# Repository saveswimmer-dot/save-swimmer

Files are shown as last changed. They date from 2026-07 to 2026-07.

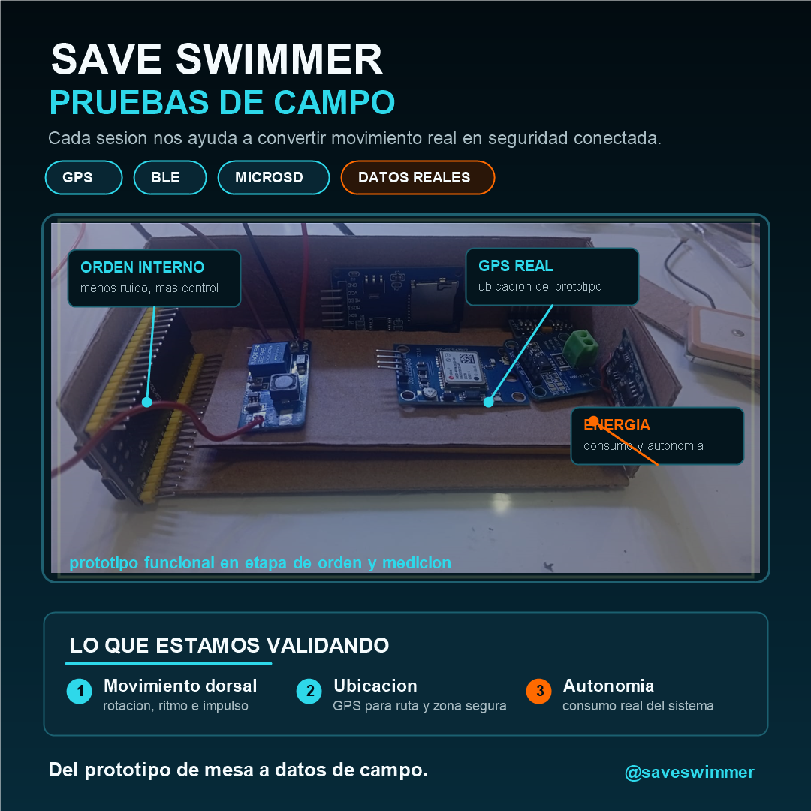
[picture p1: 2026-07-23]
redes/SS-POST-PRUEBAS-CAMPO-V004.png

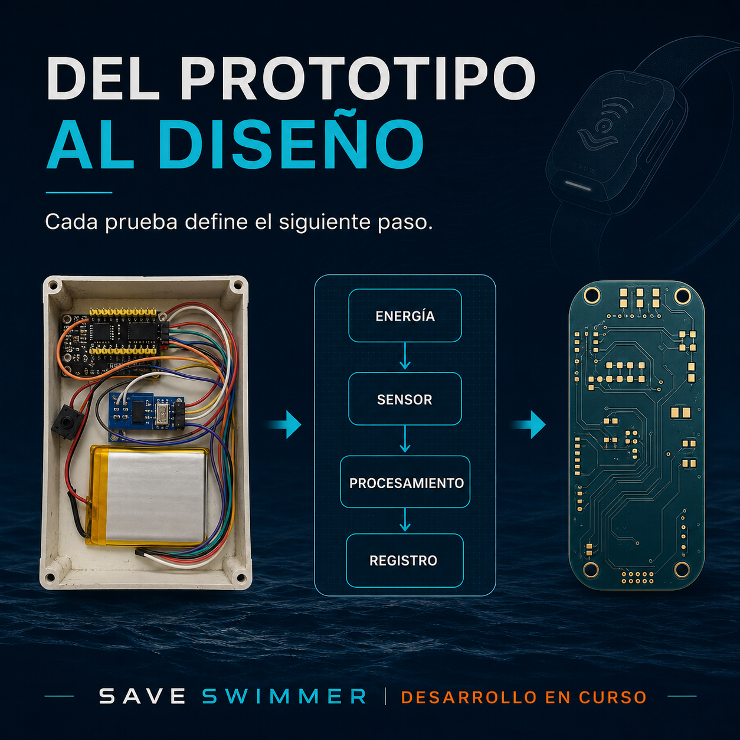
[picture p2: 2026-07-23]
campana_financiamiento/post_redes_del_prototipo_al_diseno_v001.png

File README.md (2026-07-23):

# Save Swimmer

Connected safety and monitoring for open-water swimmers.

Save Swimmer is a working early prototype of a connected safety and monitoring system for open-water swimmers. The project explores how a dorsal wearable, Android apps, GPS, motion sensors, local logging, and session reports can provide more context than location alone.

This is not a certified rescue device. It is a prototype for validating data capture, swimmer context, app workflows, and future early-warning behavior.

## Why It Matters

Open-water swimmers often train far from shore. Family members, coaches, or event organizers may know the intended route, but not the swimmer's real context in the water.

GPS can show location and speed, but it does not always explain whether the swimmer is moving normally, drifting, pausing, rotating differently, or showing unusual movement patterns. Save Swimmer focuses on connected awareness: location, movement, session state, and trusted-contact workflows.

## Current Prototype

The current project includes:

- a dorsal wearable prototype;
- ESP32-based firmware;
- IMU/motion sensor capture;
- GPS/session data capture;
- Bluetooth LE communication;
- microSD CSV logging;
- Android app concepts for athlete, family, coach, and field testing;
- CSV/session analysis tools;
- report and visualization work for rotation, alignment, movement, and GPS speed;
- hardware, enclosure, and wearable-mounting design notes.

## Repository Map

- `SaveSwimmer_Lite_BLE_Viewer_V054/` - current firmware prototype sketch.
- `android/SaveSwimmerAthlete/` - athlete-facing Android app prototype.
- `android/SaveSwimmerFamily/` - family/emergency-contact app prototype.
- `android/SaveSwimmerCoachLive/` - optional coach/event live monitoring prototype.
- `android/SaveSwimmerFieldViewer/` - field testing and live data review app.
- `backend/` - backend/ngrok test support and local data.
- `herramientas/` - CSV/reporting and analysis tools.
- `reportes_atleta/` - athlete report generation work.
- `datasets/` - test data and evidence datasets.
- `diseno_3d/` - enclosure and 3D mockup files.
- `diseno_arnes/` - dorsal harness/mounting pattern for field testing.
- `outputs/` - project notes, cost analysis, and technical planning documents.
- `redes/` and `social_posts/` - project media and public communication drafts.

## Built With

- Codex
- GPT-5.6
- Android
- Java
- ESP32
- Arduino
- Bluetooth LE
- GPS
- microSD
- CSV
- IoT
- Wearable prototyping
- Sensor data analysis
- Data visualization

## How Codex And GPT-5.6 Were Used

Codex and GPT-5.6 were used as an active development partner across the project, including:

- firmware iteration and test planning;
- Android APK versioning, UI adjustments, and debugging;
- BLE/GPS/session workflow design;
- CSV interpretation and report-generation logic;
- biomechanical reference analysis for rotation and alignment context;
- product positioning and safety-language refinement;
- Devpost submission drafting;
- README and documentation preparation;
- hardware roadmap, cost modeling, and prototype planning.

The project existed as a broader idea before OpenAI Build Week, but it was meaningfully extended during the hackathon period with Codex-assisted work across apps, firmware, reports, product documentation, and submission materials.

## Testing Notes

This project combines software and physical prototype work. Judges can review the Android source/APKs, firmware sketch, CSV/reporting tools, documentation, and demo video. The hardware prototype is intended for controlled field validation and is not presented as a finished commercial product.

Recommended review path:

1. Watch the demo video.
2. Read this README.
3. Review the current firmware in `SaveSwimmer_Lite_BLE_Viewer_V054/`.
4. Review Android prototypes under `android/`.
5. Review CSV/reporting outputs and project documentation.

## Safety Note

Save Swimmer is an early-stage prototype. It does not guarantee rescue, replace lifeguards, replace emergency services, or certify swimmer safety. Its current purpose is to validate data capture, connected monitoring workflows, and the product direction for future open-water safety support.

## Next Steps

- More controlled pool and open-water tests.
- Improved wearable mounting and waterproofing.
- Cleaner hardware layout.
- Better live synchronization.
- Improved GPS and motion interpretation.
- Family/emergency-contact workflow refinement.
- Coach/event dashboard refinement.
- International connectivity planning.

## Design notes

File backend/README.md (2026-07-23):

# Save Swimmer Backend V001

Backend minimo local para pruebas de telemetria.

## Ejecutar

Opcion recomendada en Windows, sin instalar nada:

```powershell
powershell -NoProfile -ExecutionPolicy Bypass -File .\server.ps1
```

Tambien queda disponible `server.js` para usar con Node.js si mas adelante instalamos Node normal.

Luego abrir:

```text
http://localhost:8787/
```

Vista movil para entrenador en playa:

```text
http://localhost:8787/coach.html
```

En prueba con telefono gateway y URL publica:

```text
https://URL_PUBLICA/coach.html
```

## Endpoint Principal

```text
POST http://localhost:8787/api/telemetry
Content-Type: application/json
```

Ejemplo:

```json
{
  "serial": "SS-LT-000001",
  "user": "Paula",
  "mode": "FIELD_TEST",
  "lat": -12.1609,
  "lon": -77.0309,
  "lr": 0.3,
  "fb": 1.2,
  "ud": 9.4,
  "mag": 9.8,
  "battery": 82,
  "water": true,
  "motion": "SWIMMING",
  "risk": "NORMAL"
}
```

## API

- `GET /api/health`
- `POST /api/telemetry`
- `POST /api/simulate`
- `GET /api/devices`
- `GET /api/devices/:serial/latest`
- `GET /api/devices/:serial/telemetry?limit=300`
- `GET /api/sessions`
- `GET /api/alerts/active`

## Datos

Los datos se guardan localmente en:

```text
backend/data/save_swimmer_db.json
```

Esto es prototipo. Para producto real se migraria a una base de datos robusta.

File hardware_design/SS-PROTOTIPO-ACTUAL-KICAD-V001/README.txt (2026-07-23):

SAVE SWIMMER - ESQUEMA KICAD DEL PROTOTIPO ACTUAL V001
Fecha: 2026-06-08

OBJETIVO
Representar las conexiones modulares que actualmente forman el prototipo:

- Bateria LiPo
- TP4056 con proteccion
- Interruptor general
- MT3608 ajustado a 5.0 V
- ESP32-S3 DevKit N16R8
- MPU6050
- Modulo microSD SPI con conversion a 3.3 V
- Capacitores de estabilizacion

ARCHIVO PRINCIPAL RECOMENDADO
SS-PROTOTIPO-ACTUAL-BLOQUES-V001.kicad_sch

Este archivo usa el formato moderno de KiCad 10 y presenta el prototipo como
diagrama modular editable. Es la mejor entrada para comprender la arquitectura
y agregar los siguientes bloques.

ARCHIVO AUXILIAR DETALLADO
SS-PROTOTIPO-ACTUAL-V001.sch

El archivo .sch usa formato legado y documenta pines y etiquetas con mayor
detalle. Debe considerarse referencia auxiliar; la tabla PINOUT es la fuente
principal para conexiones fisicas confirmadas.

VISTA RAPIDA
export/SS-PROTOTIPO-ACTUAL-BLOQUES-V001.pdf

IMPORTANTE
- Es un diagrama del prototipo modular, NO un esquema listo para fabricar PCB.
- Confirmar fisicamente SDA/SCL. El plano propone GPIO8/GPIO9 porque el
  firmware V044 usa Wire.begin() sin pines explicitos.
- Los GPIO SPI microSD si estan confirmados en firmware V044:
  CS 10, MOSI 11, SCK 12, MISO 13.
- La microSD figura a 5 V porque esa conexion fue la validada durante pruebas.
- Ajustar el MT3608 antes de conectar el ESP32.
- Revisar polaridad de bateria, TP4056 y capacitores electroliticos.

SIGUIENTE VERSION
Cuando se confirmen GPS, sensor de agua, medicion INA219, LED 360 y activacion
magnetica se agregaran como una nueva version del esquema. La PCB final
reemplazara los modulos por componentes y footprints exactos.

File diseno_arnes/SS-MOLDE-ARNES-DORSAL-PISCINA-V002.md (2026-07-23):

# Save Swimmer - Molde soporte piscina V002

Este molde reemplaza al V001 para la prueba con el prototipo actual.

Medida confirmada del dispositivo:

- Largo: 135 mm
- Ancho: 80 mm
- Alto: 40 mm

Archivo:

- `SS-MOLDE-ARNES-DORSAL-PISCINA-V002.svg`

Uso recomendado:

1. Imprimir al 100%.
2. Verificar la regla de control de 100 mm.
3. Cortar primero una muestra barata.
4. Probar en seco con el dispositivo dentro de una funda.
5. Recién después cortar neopreno/tela definitiva.

Idea de construcción:

- Base dorsal de 210 x 150 mm aproximadamente.
- Dos correas elásticas horizontales sobre el dispositivo.
- Dos tirantes simples para que no baje.
- Anclajes reforzados con costura cuadrada + X.
- Tapa superior opcional si el dispositivo se mueve.

Material sugerido:

- Neopreno 2 a 4 mm, goma EVA forrada o tela deportiva firme.
- Elástico ancho de 50 a 70 mm para sujetar el dispositivo.
- Elástico de 35 a 45 mm para tirantes.
- Velcro ancho.
- Hilo poliéster.

Punto crítico:

El prototipo es alto. La prioridad no es hidrodinámica perfecta, sino que no se mueva, no rebote y mantenga orientación constante durante la prueba.

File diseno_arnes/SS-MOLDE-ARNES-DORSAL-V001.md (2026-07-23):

# Save Swimmer - Molde arnes dorsal V001

Archivo principal:

- `SS-MOLDE-ARNES-DORSAL-V001.svg`

Uso:

1. Abrir el SVG en navegador, Illustrator, Inkscape o Corel.
2. Imprimir al 100%.
3. Verificar la regla de control de 100 mm.
4. Cortar primero una muestra barata en tela o cartulina antes de cortar neopreno.

Piezas:

- Pieza A: espalda dorsal, cortar 1 en neopreno.
- Pieza B: base de bolsillo para el dispositivo.
- Pieza C: retencion frontal elastica.
- Pieza D: tapa opcional con velcro.
- Pieza E: correas de hombro, cortar 2.
- Pieza F: correa baja de estabilizacion.

Material sugerido:

- Neopreno 2 a 3 mm o tela deportiva firme.
- Cinta elastica de 35 a 40 mm.
- Velcro suave.
- Bies elastico para bordes.
- Hilo poliester.

Notas importantes:

- El dispositivo debe quedar centrado entre omoplatos.
- No debe tocar cuello ni axilas.
- El bolsillo debe tener drenaje.
- Reforzar uniones con costura cuadrada y X.
- Esta es una muestra de calce, no un diseno final homologado.

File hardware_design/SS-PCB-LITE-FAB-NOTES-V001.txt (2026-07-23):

SAVE SWIMMER - PCB LITE CONCEPT V001
Fecha: 2026-06-04
Estado: boceto conceptual, NO enviar a fabricar como Gerber final.

Objetivo:
Definir una primera arquitectura fisica compacta para Save Swimmer Lite, pasando de modulos de prototipo a una PCB integrada.

Medida conceptual:
- PCB: 78 mm x 38 mm, contorno tipo capsula.
- Carcasa objetivo inicial: 85 mm x 45 mm x 18 mm aprox.
- El prototipo actual en caja 110 mm x 70 mm x 30 mm confirma que hay espacio para reducir al integrar modulos.

Version Lite contemplada:
- ESP32-S3 como cerebro principal.
- IMU centrada para rotacion dorsal.
- BLE para configuracion cercana.
- GSM/LTE/NB-IoT pendiente de seleccion para datos remotos.
- GNSS/GPS pendiente de validacion real en costa/playa.
- microSD o flash para registro local.
- Sensor de agua.
- LEDs 360 por difusor lateral.
- Boton sellado o activacion magnetica.
- Cargador LiPo y regulacion integrados.
- Bateria LiPo plana separada de antenas.

Zonas criticas:
1. RF / antenas
   - No colocar bateria, cobre, tornillos ni masas grandes sobre antenas.
   - Separar antena celular, GNSS y BLE si se usan antenas diferentes.
   - Requiere revision RF antes de fabricar.

2. IMU
   - Debe estar lo mas centrada posible.
   - Debe tener serigrafia clara de ejes: DER/IZQ/ARRIBA/ABAJO.
   - La carcasa debe orientar siempre igual el dispositivo en espalda.

3. Energia
   - El MT3608 modular no debe ser la solucion final.
   - Usar regulador eficiente, power path y proteccion bateria.
   - Debe permitir apagado real o ultra bajo consumo.

4. microSD
   - Es muy util para desarrollo.
   - Para producto final podria cambiarse por flash interna para mejorar sellado.

5. Sensor de agua
   - Debe resistir salitre, corrosion y falsos positivos.
   - La logica debe distinguir mojado breve, inicio real y salida del agua.

6. LEDs
   - La luz no debe quedar solo en la tapa superior.
   - Usar difusor lateral/perimetral para visibilidad 360.

No listo para fabrica hasta definir:
- Modulo celular final y operador/SIM/eSIM.
- Antena final y prueba RF.
- Bateria final.
- Metodo de carga final: magnetico, pogo sellado o Qi.
- Carcasa y junta de sellado.
- Huellas exactas de componentes.
- Esquema electrico completo.
- Reglas PCB: capas, grosor, impedancia, anchos de pista, corriente, tierra.
- Prueba de consumo, reposo, temperatura y estanqueidad.

Decision recomendada:
Usar este V001 como mapa de producto y conversacion con disenador PCB, no como plano final.

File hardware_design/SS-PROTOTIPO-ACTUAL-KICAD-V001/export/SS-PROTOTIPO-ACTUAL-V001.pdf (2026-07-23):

1 | 2 | 3 | 4 | 5 | 6
1 | 2 | 3 | 4 | 5 | 6

AB

C

D

AB

C

D Date: 2026-06-08

Size: A4 | Rev: V001
KiCad E.D.A. 10.0.3 | Id: 1/1

Title: SAVE SWIMMER - PROTOTIPO ACTUAL V001

File: SS-PROTOTIPO-ACTUAL-V001.sch

Sheet: /

Save Swimmer

Esquema modular para pruebas. NO enviar a fabricar.

I2C GPIO8/GPIO9 pendiente de confirmar fisicamente.

microSD alimentada a 5V segun pruebas actuales.

Firmware de referencia: SS-LITE-BLE-SD-V1-044 +5V_SYS USB_5V_IN
GND | +3V3

GND
BAT_PROT+

+3V3 GND

GND

GND

# I2C_SCL_GPIO9 GND +5V_SYS GND

SD_SCK_GPIO12

I2C_SDA_GPIO8 GND

SD_CS_GPIO10 USB_5V_IN

BAT_SW+

BAT_RAW+
GND | MPU_INT_NC

SD_MISO_GPIO13 BAT_RAW+

SD_MOSI_GPIO11

I2C_SCL_GPIO9
SD_CS_GPIO10
SD_MOSI_GPIO11
SD_SCK_GPIO12
SD_MISO_GPIO13 GND | +5V_SYS GND
GND +3V3
I2C_SDA_GPIO8 BAT_PROT+ | +5V_SYS | GND

BAT_SW+ +5V_SYS

GND

GND

5 OUT+

4 B-
6 OUT- Flujo de energia actual: LiPo -> TP4056 protegido -> interruptor -> MT3608 ajustado a 5.0V -> ESP32-S3 + microSD

ADVERTENCIA: verificar polaridad y ajustar MT3608 antes de conectar el ESP32. No cargar una bateria danada o usada sin supervision.

El MPU6050 usa 3V3. El modulo microSD probado usa 5V por incluir regulador/conversion de nivel.

GPIO SPI confirmados por firmware V044: CS=10, MOSI=11, SCK=12, MISO=13.

I2C propuesto para documentacion: SDA=GPIO8, SCL=GPIO9. Confirmar cableado real antes de usar este plano como referencia.

C1 1000uF recomendado cerca de la carga de 5V. C2/C3 son ceramicos 104 = 100nF. 3 OUT+

2 IN-

4 OUT-

MISO

2 IN-3 B+

1 IN+ | MPU6050 detectado en direccion I2C 0x68

# SCK ENERGIA Y CARGA

Alimentacion en pruebas de bateria: MT3608 = 5.06V; microSD conectada a 5V

1 IN+

MOSI

INT no conectado

VCC
GND
SCL SDA

AD0=GND

VCC 5V probado GND

CS microSD SPI: GPIO10 CS / GPIO11 MOSI / GPIO12 SCK / GPIO13 MISO

CONEXIONES CONFIRMADAS

# CONTROL Y SENSORES

BLE integrado en ESP32-S3; no requiere cableado adicional J1
ENTRADA_CARGA_5V SW1

INTERRUPTOR_GENERAL

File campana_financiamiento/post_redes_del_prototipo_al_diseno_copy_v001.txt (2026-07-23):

DEL PROTOTIPO AL DISENO

Save Swimmer comenzó con una pregunta:

¿Cómo podemos generar información útil que ayude a reducir el tiempo en el que nadie sabe qué sucede con un nadador de aguas abiertas?

Hoy seguimos avanzando desde un prototipo experimental hacia una arquitectura electrónica más ordenada.

Cada prueba nos permite definir:

- qué componentes realmente aportan valor;
- cómo mejorar la estabilidad y autonomía;
- qué información puede interpretarse de forma clara;
- cómo reducir el tamaño futuro del dispositivo;
- qué debe validarse antes de pensar en fabricación.

Todavía no estamos mostrando un producto final. Estamos construyendo y documentando cada paso para llegar a uno.

Save Swimmer
Seguridad conectada para aguas abiertas.

Síguenos y acompaña el desarrollo:
Instagram: @saveswimmer
TikTok: @saveswimmer
Facebook: Save Swimmer

#SaveSwimmer #AguasAbiertas #SeguridadAcuatica #TecnologiaPeruana #Prototipo #Desarrollo

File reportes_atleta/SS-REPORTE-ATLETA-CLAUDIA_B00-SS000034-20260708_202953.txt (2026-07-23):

SAVE SWIMMER - REPORTE AUTOMÁTICO DE SESIÓN
Atleta: CLAUDIA B00
Archivo: SS000034.CSV
Duración: 00:11 | Muestras: 103

Rotación: baja. giraste poco el cuerpo; puede faltar rolido para preparar mejor la brazada.
Alineación: estable. el cuerpo se mantuvo bastante parejo.
Impulso: suave. empuje suave; puede ser nado tranquilo o poca energía de impulso.
Ritmo: sin ciclo claro | Brazadas/ciclos detectados: 0
GPS: 0 puntos válidos | Distancia aproximada: 0 m
Mejor tramo: 00:04 a 00:15
Cambio observado: no hubo un cambio fuerte entre inicio y final.

Nota: lectura técnica/deportiva experimental. No es diagnóstico médico.

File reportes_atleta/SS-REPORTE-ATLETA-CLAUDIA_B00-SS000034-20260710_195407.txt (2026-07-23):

SAVE SWIMMER - REPORTE AUTOMÁTICO DE SESIÓN
Atleta: CLAUDIA B00
Archivo: SS000034.CSV
Duración: 00:11 | Muestras: 103
Tipo de sesión: SIN_NADO | sin nado confirmado: prueba quieta, muy corta o con energía insuficiente.

Rotación: baja. giraste poco el cuerpo; puede faltar rolido para preparar mejor la brazada.
Alineación: estable. el cuerpo se mantuvo bastante parejo.
Impulso: suave. empuje suave; puede ser nado tranquilo o poca energía de impulso.
Ritmo: sin nado confirmado | Movimientos detectados: 0
GPS: 0 puntos válidos | Distancia aproximada: 0 m
Mejor tramo: 00:04 a 00:15
Cambio observado: no hubo un cambio fuerte entre inicio y final.

Nota: lectura técnica/deportiva experimental. No es diagnóstico médico.

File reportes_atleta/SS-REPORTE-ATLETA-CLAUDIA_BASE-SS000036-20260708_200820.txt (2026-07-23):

SAVE SWIMMER - REPORTE AUTOMÁTICO DE SESIÓN
Atleta: CLAUDIA BASE
Archivo: SS000036.CSV
Duración: 00:37 | Muestras: 265

Rotación: correcta. el giro corporal estuvo dentro de una zona útil para nadar.
Alineación: estable. el cuerpo se mantuvo bastante parejo.
Impulso: suave. empuje suave; puede ser nado tranquilo o poca energía de impulso.
Ritmo: 2.7 s/ciclo | Brazadas/ciclos detectados: 12
GPS: 0 puntos válidos | Distancia aproximada: 0 m
Mejor tramo: 00:20 a 00:50
Cambio observado: al final cambió la alineación; revisar si aparece cansancio.

Nota: lectura técnica/deportiva experimental. No es diagnóstico médico.

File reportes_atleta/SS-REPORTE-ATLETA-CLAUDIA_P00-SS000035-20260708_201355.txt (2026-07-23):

SAVE SWIMMER - REPORTE AUTOMÁTICO DE SESIÓN
Atleta: CLAUDIA P00
Archivo: SS000035.CSV
Duración: 00:23 | Muestras: 151

Rotación: baja. giraste poco el cuerpo; puede faltar rolido para preparar mejor la brazada.
Alineación: estable. el cuerpo se mantuvo bastante parejo.
Impulso: suave. empuje suave; puede ser nado tranquilo o poca energía de impulso.
Ritmo: sin ciclo claro | Brazadas/ciclos detectados: 0
GPS: 0 puntos válidos | Distancia aproximada: 0 m
Mejor tramo: 00:00 a 00:23
Cambio observado: no hubo un cambio fuerte entre inicio y final.

Nota: lectura técnica/deportiva experimental. No es diagnóstico médico.

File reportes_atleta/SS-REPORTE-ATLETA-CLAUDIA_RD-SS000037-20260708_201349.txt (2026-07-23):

SAVE SWIMMER - REPORTE AUTOMÁTICO DE SESIÓN
Atleta: CLAUDIA RD
Archivo: SS000037.CSV
Duración: 00:24 | Muestras: 146

Rotación: baja. giraste poco el cuerpo; puede faltar rolido para preparar mejor la brazada.
Alineación: estable. el cuerpo se mantuvo bastante parejo.
Impulso: suave. empuje suave; puede ser nado tranquilo o poca energía de impulso.
Ritmo: 2.0 s/ciclo | Brazadas/ciclos detectados: 11
GPS: 0 puntos válidos | Distancia aproximada: 0 m
Mejor tramo: 00:08 a 00:32
Cambio observado: no hubo un cambio fuerte entre inicio y final.

Nota: lectura técnica/deportiva experimental. No es diagnóstico médico.

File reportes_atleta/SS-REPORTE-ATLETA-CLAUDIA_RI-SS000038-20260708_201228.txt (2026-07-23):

SAVE SWIMMER - REPORTE AUTOMÁTICO DE SESIÓN
Atleta: CLAUDIA RI
Archivo: SS000038.CSV
Duración: 00:31 | Muestras: 235

Rotación: asimetría. un lado giró más que el otro. Lado dominante: IZQ.
Alineación: irregular. hubo mucha variación; puede aparecer cansancio o pérdida de línea corporal.
Impulso: normal. empuje controlado y parejo.
Ritmo: 2.1 s/ciclo | Brazadas/ciclos detectados: 14
GPS: 0 puntos válidos | Distancia aproximada: 0 m
Mejor tramo: 00:00 a 00:30
Cambio observado: al final cambió la alineación; revisar si aparece cansancio.

Nota: lectura técnica/deportiva experimental. No es diagnóstico médico.

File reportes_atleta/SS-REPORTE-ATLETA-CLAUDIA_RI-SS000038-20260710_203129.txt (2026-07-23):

SAVE SWIMMER - REPORTE AUTOMÁTICO DE SESIÓN
Atleta: CLAUDIA RI
Archivo: SS000038.CSV
Duración: 00:31 | Muestras: 235
Tipo de sesión: NO_CLASIFICADO | datos no clasificados: revisar contexto de prueba antes de sacar conclusiones.

Rotación: baja. giraste poco el cuerpo; puede faltar rolido para preparar mejor la brazada.
Alineación: irregular. hubo mucha variación; puede aparecer cansancio o pérdida de línea corporal.
Impulso: normal. empuje controlado y parejo.
Ritmo: sin nado confirmado | Movimientos detectados: 0
GPS: 0 puntos válidos | Distancia aproximada: 0 m
Mejor tramo: 00:00 a 00:30
Cambio observado: al final cambió la alineación; revisar si aparece cansancio.

Nota: lectura técnica/deportiva experimental. No es diagnóstico médico.

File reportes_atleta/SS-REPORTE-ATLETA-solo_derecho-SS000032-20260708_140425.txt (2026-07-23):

SAVE SWIMMER - REPORTE AUTOMÁTICO DE SESIÓN
Atleta: solo derecho
Archivo: SS000032.CSV
Duración: 00:11 | Muestras: 107

Rotación: asimetría. un lado giró más que el otro. Lado dominante: DER.
Alineación: estable. el cuerpo se mantuvo bastante parejo.
Impulso: normal. empuje controlado y parejo.
Ritmo: 1.6 s/ciclo | Brazadas/ciclos detectados: 5
GPS: 107 puntos válidos | Distancia aproximada: 1.2 m
Mejor tramo: 00:00 a 00:11
Cambio observado: no hubo un cambio fuerte entre inicio y final.

Nota: lectura técnica/deportiva experimental. No es diagnóstico médico.

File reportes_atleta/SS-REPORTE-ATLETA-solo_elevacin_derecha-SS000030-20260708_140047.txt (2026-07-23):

SAVE SWIMMER - REPORTE AUTOMÁTICO DE SESIÓN
Atleta: solo elevacin derecha
Archivo: SS000030.CSV
Duración: 00:46 | Muestras: 367

Rotación: baja. giraste poco el cuerpo; puede faltar rolido para preparar mejor la brazada.
Alineación: variable. la postura cambió por momentos.
Impulso: normal. empuje controlado y parejo.
Ritmo: sin ciclo claro | Brazadas/ciclos detectados: 0
GPS: 0 puntos válidos | Distancia aproximada: 0 m
Mejor tramo: 00:00 a 00:30
Cambio observado: al final subió el esfuerzo y cambió la alineación; posible fatiga o técnica menos estable.

Nota: lectura técnica/deportiva experimental. No es diagnóstico médico.

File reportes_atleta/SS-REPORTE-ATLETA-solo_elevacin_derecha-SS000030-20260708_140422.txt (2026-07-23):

SAVE SWIMMER - REPORTE AUTOMÁTICO DE SESIÓN
Atleta: solo elevacin derecha
Archivo: SS000030.CSV
Duración: 00:46 | Muestras: 367

Rotación: asimetría. un lado giró más que el otro. Lado dominante: DER.
Alineación: variable. la postura cambió por momentos.
Impulso: normal. empuje controlado y parejo.
Ritmo: 2.6 s/ciclo | Brazadas/ciclos detectados: 17
GPS: 0 puntos válidos | Distancia aproximada: 0 m
Mejor tramo: 00:00 a 00:30
Cambio observado: al final subió el esfuerzo y cambió la alineación; posible fatiga o técnica menos estable.

Nota: lectura técnica/deportiva experimental. No es diagnóstico médico.

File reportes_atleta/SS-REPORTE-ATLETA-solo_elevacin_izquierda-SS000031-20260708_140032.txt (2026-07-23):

SAVE SWIMMER - REPORTE AUTOMÁTICO DE SESIÓN
Atleta: solo elevacin izquierda
Archivo: SS000031.CSV
Duración: 00:38 | Muestras: 291

Rotación: asimetría. un lado giró más que el otro. Lado dominante: IZQ.
Alineación: variable. la postura cambió por momentos.
Impulso: normal. empuje controlado y parejo.
Ritmo: 3.2 s/ciclo | Brazadas/ciclos detectados: 9
GPS: 0 puntos válidos | Distancia aproximada: 0 m
Mejor tramo: 00:00 a 00:30
Cambio observado: al final subió el esfuerzo y cambió la alineación; posible fatiga o técnica menos estable.

Nota: lectura técnica/deportiva experimental. No es diagnóstico médico.

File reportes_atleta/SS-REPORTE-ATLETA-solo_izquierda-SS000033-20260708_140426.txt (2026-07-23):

SAVE SWIMMER - REPORTE AUTOMÁTICO DE SESIÓN
Atleta: solo izquierda
Archivo: SS000033.CSV
Duración: 00:09 | Muestras: 84

Rotación: asimetría. un lado giró más que el otro. Lado dominante: IZQ.
Alineación: irregular. hubo mucha variación; puede aparecer cansancio o pérdida de línea corporal.
Impulso: alto. hubo picos fuertes; mirar si fue fuerza útil o movimiento brusco.
Ritmo: 1.6 s/ciclo | Brazadas/ciclos detectados: 5
GPS: 84 puntos válidos | Distancia aproximada: 0.1 m
Mejor tramo: 00:00 a 00:09
Cambio observado: al final subió el esfuerzo y cambió la alineación; posible fatiga o técnica menos estable.

Nota: lectura técnica/deportiva experimental. No es diagnóstico médico.

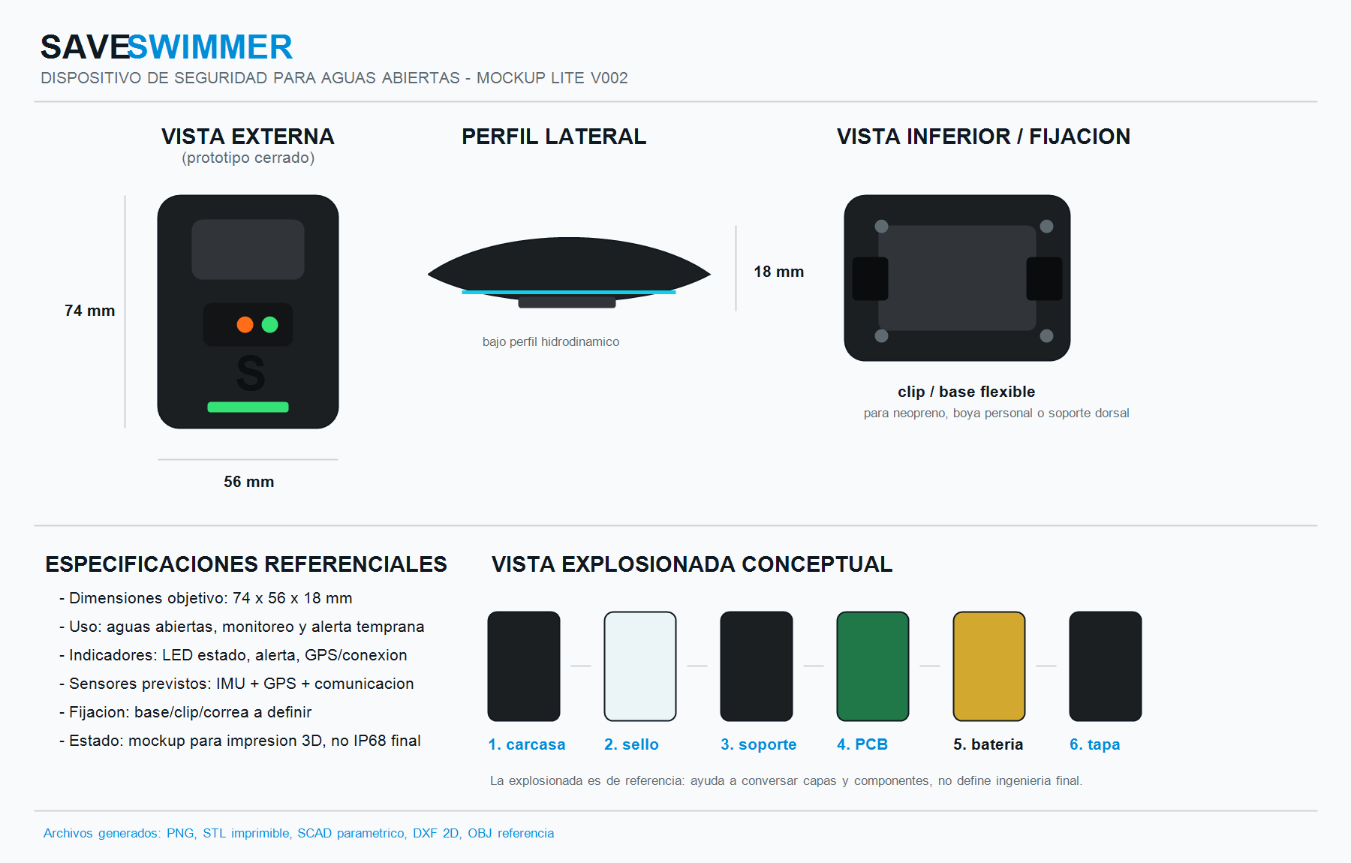
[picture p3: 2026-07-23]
diseno_3d/SS-CARCASA-LITE-MOCKUP-V002/SS-CARCASA-LITE-MOCKUP-V002.png

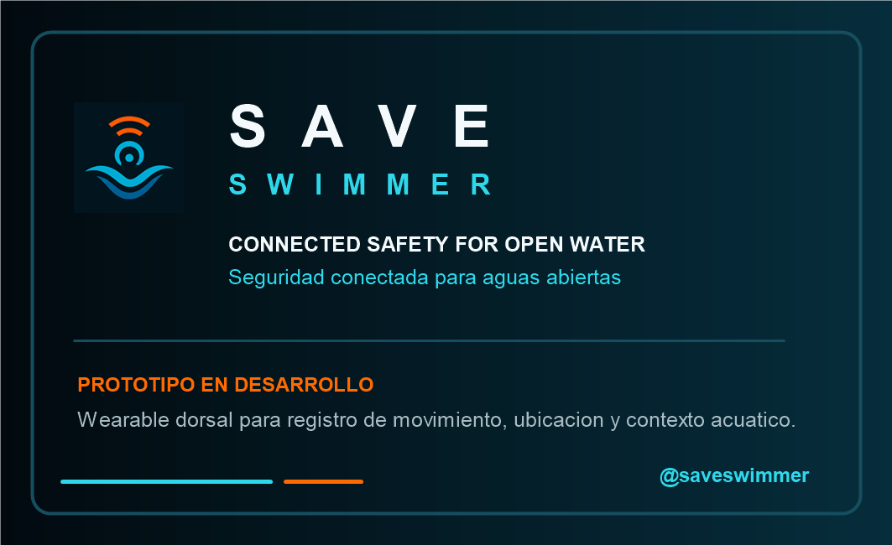
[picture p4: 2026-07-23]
assets/branding/SS-TARJETA-PRESENTACION-FRENTE-V001.png

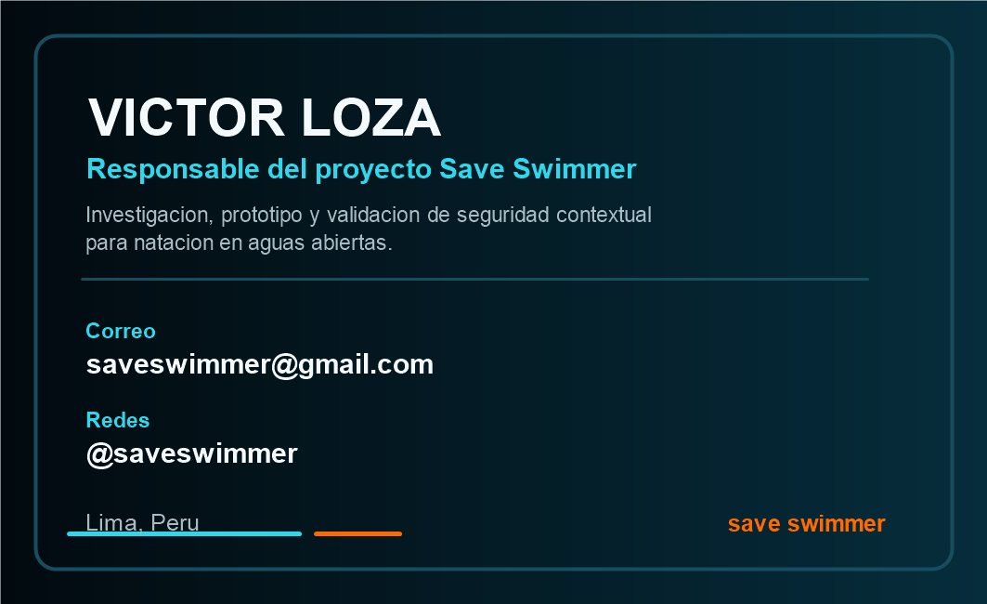
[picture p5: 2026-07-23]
assets/branding/SS-TARJETA-PRESENTACION-DORSO-V001.png

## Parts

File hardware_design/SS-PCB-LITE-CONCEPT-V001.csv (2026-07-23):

id | bloque | componente_o_zona | medida_aprox_mm | ubicacion_sugerida | funcion | notas_para_fabricacion
PCB | Base | PCB principal Save Swimmer Lite | 78 x 38 x 1.0/1.2 | Interior carcasa dorsal | Soporte electronico principal | Medida conceptual para reducir desde caja prototipo 110 x 70 x 30; ajustar a carcasa real
PCB | Forma | Contorno tipo capsula hidrodinamica | 78 x 38 | Perimetro completo | Reducir aristas y facilitar sellado | Bordes redondeados; considerar carcasa 85 x 45 x 18 aprox como primer objetivo
RF | Zona antenas | Zona libre de cobre para RF | 20 x 38 | Extremo superior/cola del PCB | Permitir antena GSM/GNSS/BLE | No colocar bateria ni planos metalicos encima; requiere revision RF
MCU | Procesamiento | ESP32-S3-WROOM-1 N16R8 | 18 x 26 | Centro-derecha | Procesamiento BLE/WiFi/IMU/gateway local | Mantener keepout de antena ESP si se usa antena del modulo; alternativa final chip/PCB antenna requiere diseno RF
IMU | Sensores | IMU MPU6050/ICM20602/ICM-42688 footprint TBD | 4 x 4 a 10 x 10 | Centro fisico del PCB | Lectura de movimiento dorsal y rotacion | Debe ubicarse centrada y alineada con eje del cuerpo; marcar orientacion en serigrafia
SD | Memoria | microSD o memoria flash | 15 x 14 | Inferior derecha | Registro de sesiones y datasets | microSD util en desarrollo; producto final podria usar flash interna para mejor sellado
PWR | Carga | Cargador LiPo + proteccion | 12 x 10 | Inferior izquierda | Carga y proteccion bateria | Reemplaza TP4056 modular por IC de carga integrado; definir carga magnetica/Qi/pogo
PWR | Regulacion | Boost/buck/power path | 14 x 10 | Centro inferior | Alimentacion estable 3.3V/4V/5V segun modulos | MT3608 conceptual; final debe usar regulador eficiente y bajo consumo en reposo
CELL | Comunicacion | GSM/LTE/NB-IoT modulo TBD | 18 x 16 a 30 x 30 | Extremo RF/izquierda | Datos remotos | SOS y ubicacion si aplica | Seleccionar modulo compatible Peru; SIM800L 2G no recomendado como final si red 2G no esta garantizada
SIM | Identidad | SIM/eSIM/MFF2 o nanoSIM sellada | 8 x 6 a 12 x 15 | Cerca modulo celular | Identidad celular y plan SS | Producto sellado deberia evitar SIM removible por usuario; evaluar eSIM/MFF2 o SIM interna
GNSS | Ubicacion | GPS/GNSS modulo o receptor integrado | 10 x 10 a 16 x 12 | Zona RF | Ubicacion del nadador | Antena activa/ceramica necesita vista al cielo; agua reduce senal; validar en playa
BLE | Local | BLE integrado ESP32-S3 | Incluido MCU | ESP32 | Configuracion cercana y pruebas | BLE no sirve remoto; solo cerca del telefono
WATER | Agua | Sensor de agua por electrodos/capacitivo | 2 pads externos | Carcasa exterior | Detectar ingreso/salida del agua | Debe tener proteccion corrosion/salitre; definir logica para no falsos positivos
LED | Visual | LEDs estado/SOS 360 | 4 a 8 LEDs perimetro | Borde o difusor lateral | Visibilidad nocturna/estado | No poner solo arriba; usar difusor perimetral para visibilidad 360
BTN | Entrada | Boton fisico o reed/hall magnetico | 5 x 5 | Lateral sellado | Encendido/SOS/cancelar | Preferible activacion magnetica o boton sellado IP; evitar perforaciones debiles
MOTOR | Haptico | Vibrador mini opcional | 10 x 3 | Centro inferior | Confirmacion tactil/SOS | Opcional; aumenta consumo y complejidad
BATT | Energia | Bateria LiPo plana | 45 x 30 x 4 a 60 x 35 x 5 | Bajo PCB o placa separada | Energia del dispositivo | No va sobre antenas; requiere proteccion mecanica y termica
CONN | Programacion | Pads pogo/debug | 6 pads | Parte inferior o lateral | Carga firmware y diagnostico | Evitar conector abierto; usar pads internos o magneticos
ENC | Carcasa | Carcasa estimada Lite | 85 x 45 x 18 aprox | Exterior | Proteccion IP y ergonomia | Objetivo preliminar; depende de bateria, antena y sellado
CERT | Certificacion | IP68/seguridad/RF | No aplica | Proyecto | Validacion legal y comercial | PCB final debe contemplar pruebas de estanqueidad, salinidad, RF y bateria

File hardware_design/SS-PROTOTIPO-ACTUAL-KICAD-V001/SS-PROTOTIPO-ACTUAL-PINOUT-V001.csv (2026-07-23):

bloque | pin_modulo | conexion | estado | observacion
ESP32-S3 | 5V | +5V_SYS | CONFIRMADO | Alimentacion desde MT3608 ajustado aproximadamente a 5.06 V
ESP32-S3 | GND | GND | CONFIRMADO | Tierra comun obligatoria
ESP32-S3 | 3V3 | MPU6050 VCC | CONFIRMADO | No alimentar el MPU6050 desde 5 V en este esquema
ESP32-S3 | GPIO8 | MPU6050 SDA | PENDIENTE_CONFIRMAR | Firmware usa Wire.begin() sin pines explicitos
ESP32-S3 | GPIO9 | MPU6050 SCL | PENDIENTE_CONFIRMAR | Firmware usa Wire.begin() sin pines explicitos
ESP32-S3 | GPIO10 | microSD CS | CONFIRMADO_FIRMWARE | SS-LITE-BLE-SD-V1-044
ESP32-S3 | GPIO11 | microSD MOSI | CONFIRMADO_FIRMWARE | SS-LITE-BLE-SD-V1-044
ESP32-S3 | GPIO12 | microSD SCK | CONFIRMADO_FIRMWARE | SS-LITE-BLE-SD-V1-044
ESP32-S3 | GPIO13 | microSD MISO | CONFIRMADO_FIRMWARE | SS-LITE-BLE-SD-V1-044
microSD | VCC | +5V_SYS | CONFIRMADO_PRUEBAS | Modulo con regulador y conversion de nivel a 3.3 V
TP4056 | B+/B- | Bateria LiPo | CONFIRMAR_POLARIDAD | Usar modulo con proteccion
TP4056 | OUT+ | Interruptor general | CONFIRMADO_CONCEPTO | El interruptor corta alimentacion hacia MT3608
TP4056 | OUT- | GND | CONFIRMADO_CONCEPTO | Tierra comun
MT3608 | IN+ | BAT_SW+ | CONFIRMADO_CONCEPTO | Entrada posterior al interruptor
MT3608 | OUT+ | +5V_SYS | CONFIRMADO_PRUEBAS | Ajustar antes de conectar carga
C1 | 1000uF | +5V_SYS/GND | RECOMENDADO | Cerca de carga con picos
C2 | 100nF | +5V_SYS/GND | RECOMENDADO | Ceramico 104
C3 | 100nF | +3V3/GND | RECOMENDADO | Ceramico 104 cerca de MPU6050

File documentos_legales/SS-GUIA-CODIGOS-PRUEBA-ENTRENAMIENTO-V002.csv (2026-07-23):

codigo | grupo | rotacion | dedos | patada | respiracion | entorno | duracion_sugerida | descripcion | uso_en_app | lectura_esperada
B00 | base | mesa/plano | no aplica | no aplica | no aplica | seco | 30 s | Dispositivo apoyado en base plana para tomar cero fisico del prototipo. | USER=atleta / MODE=B00 | LR, FB y ROT estables; MAG cercano a gravedad; sirve para comparar contra montaje real.
P00 | base | postura de pie | no aplica | no aplica | no aplica | seco | 30 s | Dispositivo colocado en atleta, de pie y quieto, antes de entrar al agua. | USER=atleta / MODE=P00 | Detectar offset por colocacion, cinta o caja; no debe interpretarse como nado.
QAGU | base | quieto agua | no aplica | no aplica | libre | agua | 15 a 30 s | Atleta en agua sin avanzar, solo si es comodo y seguro. | USER=atleta / MODE=QAGU | Separar ruido de agua/postura de movimiento real; no forzar cara dentro del agua.
BASE | nado | natural | natural | natural | natural | piscina/mar | 25 m o 2 min | Nado libre normal sin tecnica forzada. | USER=atleta / MODE=BASE | Patron de referencia propio del atleta: rotacion, alineacion, impulso y ciclo.
RD | respiracion | natural | natural | natural | derecha | piscina/mar | 25 m | Nado libre respirando principalmente hacia derecha. | USER=atleta / MODE=RD | La respiracion deberia modificar el rolido; comparar contra BASE.
RI | respiracion | natural | natural | natural | izquierda | piscina/mar | 25 m | Nado libre respirando principalmente hacia izquierda. | USER=atleta / MODE=RI | La respiracion deberia modificar el rolido; comparar simetria derecha/izquierda.
RBDA-SP | tecnica | baja/sin rotacion | abiertos | sin | libre | piscina | 25 m | Baja rotacion, dedos abiertos y sin patada. | USER=atleta / MODE=RBDA-SP | Rotacion baja, impulso posiblemente bajo/irregular, alineacion puede caer.
RBDA-CP | tecnica | baja/sin rotacion | abiertos | con | libre | piscina | 25 m | Baja rotacion, dedos abiertos y con patada. | USER=atleta / MODE=RBDA-CP | Comparar si la patada sostiene alineacion aunque la rotacion sea baja.
RBDC-SP | tecnica | baja/sin rotacion | cerrados | sin | libre | piscina | 25 m | Baja rotacion, dedos cerrados y sin patada. | USER=atleta / MODE=RBDC-SP | Debe mostrar diferencia de impulso contra dedos abiertos si el movimiento es claro.
RBDC-CP | tecnica | baja/sin rotacion | cerrados | con | libre | piscina | 25 m | Baja rotacion, dedos cerrados y con patada. | USER=atleta / MODE=RBDC-CP | Patron de control con mayor empuje potencial que RBDA-CP.
RNDA-SP | tecnica | normal | abiertos | sin | libre | piscina | 25 m | Rotacion normal, dedos abiertos y sin patada. | USER=atleta / MODE=RNDA-SP | Evaluar si rotacion normal compensa parte del impulso bajo.
RNDA-CP | tecnica | normal | abiertos | con | libre | piscina | 25 m | Rotacion normal, dedos abiertos y con patada. | USER=atleta / MODE=RNDA-CP | Base tecnica intermedia con patada y menor empuje de mano.
RNDC-SP | tecnica | normal | cerrados | sin | libre | piscina | 25 m | Rotacion normal, dedos cerrados y sin patada. | USER=atleta / MODE=RNDC-SP | Buen codigo para aislar torso/impulso sin ayuda de patada.
RNDC-CP | tecnica | normal | cerrados | con | libre | piscina | 25 m | Rotacion normal, dedos cerrados y con patada. | USER=atleta / MODE=RNDC-CP | Candidato a referencia tecnica propia del atleta si sale consistente.
REDA-SP | tecnica | exagerada | abiertos | sin | libre | piscina | 25 m | Rotacion exagerada, dedos abiertos y sin patada. | USER=atleta / MODE=REDA-SP | Rotacion alta o excesiva; puede aumentar asimetria y afectar alineacion.
REDA-CP | tecnica | exagerada | abiertos | con | libre | piscina | 25 m | Rotacion exagerada, dedos abiertos y con patada. | USER=atleta / MODE=REDA-CP | Evaluar si patada oculta o compensa exceso de rotacion.
REDC-SP | tecnica | exagerada | cerrados | sin | libre | piscina | 25 m | Rotacion exagerada, dedos cerrados y sin patada. | USER=atleta / MODE=REDC-SP | Ver si el impulso sube pero la alineacion empeora.
REDC-CP | tecnica | exagerada | cerrados | con | libre | piscina | 25 m | Rotacion exagerada, dedos cerrados y con patada. | USER=atleta / MODE=REDC-CP | Control de exceso de rolido con maxima ayuda de empuje/patada.
FAT-2M | fatiga | natural | natural | natural | natural | piscina/mar | 2 a 4 min | Nado continuo para observar cambio de tecnica con cansancio. | USER=atleta / MODE=FAT-2M | Buscar caida de alineacion, cambio de ciclo, impulso irregular o perdida de simetria.
MAR-BASE | campo | natural | natural | natural | natural | mar | 2 a 5 min | Nado natural en mar, sin forzar tecnica. | USER=atleta / MODE=MAR-BASE | Validar GPS, senal BLE si aplica, movimiento real, oleaje y diferencia contra piscina.

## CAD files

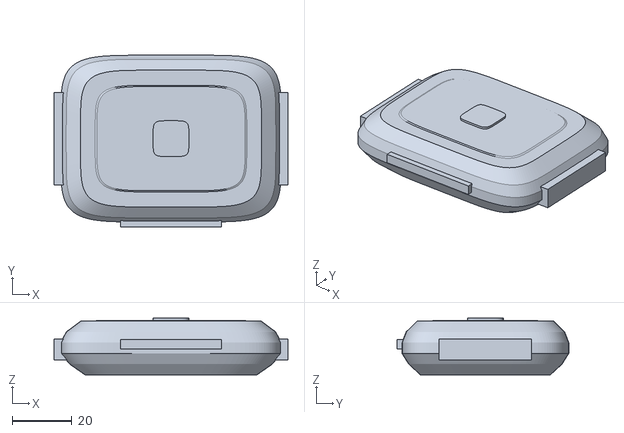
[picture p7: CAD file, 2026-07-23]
diseno_3d/SS-CARCASA-LITE-MOCKUP-V002/SS-CARCASA-LITE-MOCKUP-V002.stl
78.5 x 57.6 x 19.0

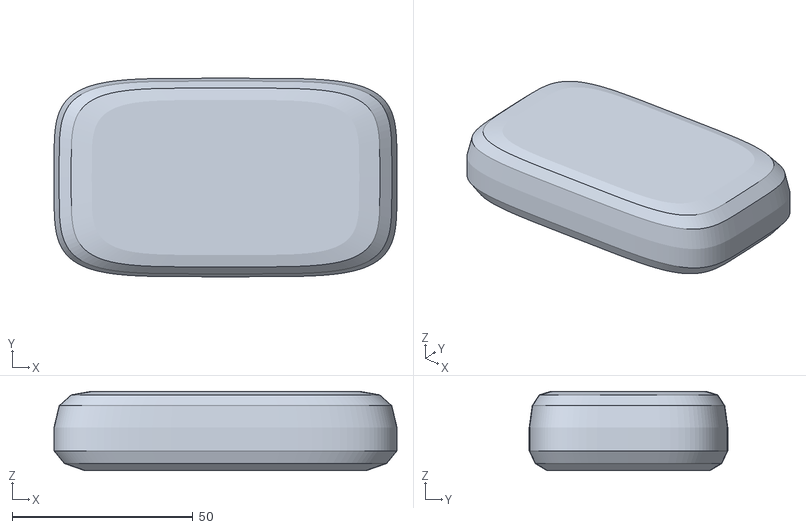
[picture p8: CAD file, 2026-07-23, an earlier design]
diseno_3d/SS-CARCASA-LITE-MOCKUP-V001/SS-CARCASA-LITE-MOCKUP-V001.stl
95.0 x 55.0 x 22.0

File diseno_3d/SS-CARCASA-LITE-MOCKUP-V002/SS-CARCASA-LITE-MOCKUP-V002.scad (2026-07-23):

// Save Swimmer Lite - mockup conceptual V002
// Unidad: mm. Lenguaje visual tipo tracker dorsal compacto.
// No es carcasa estanca final: sirve para imprimir volumen y conversar con diseno industrial.

$fn = 64;

body_len = 74;
body_w = 56;
body_h = 18;
corner_r = 12;

module rounded_box(size=[10,10,10], r=2) {
    hull() {
        for (x=[-size[0]/2+r, size[0]/2-r])
        for (y=[-size[1]/2+r, size[1]/2-r])
        for (z=[-size[2]/2+r, size[2]/2-r])
            translate([x,y,z]) sphere(r=r);
    }
}

module main_shell() {
    difference() {
        scale([1,1,0.62]) rounded_box([body_len, body_w, body_h], corner_r);
        // Curva inferior suave para que no apoye con aristas.
        translate([0, 0, -body_h*0.50])
            scale([1.05, 0.90, 0.20])
                cylinder(h=body_h, r=body_w*0.60, center=true);
    }
}

module top_lid() {
    translate([0, 0, body_h*0.30])
        scale([1,1,0.12])
            rounded_box([54, 38, 3.2], 9);
}

module lower_clip() {
    // Guia inferior para correa/base flexible. En final debe resolverse con sello/clip real.
    translate([0, -body_w*0.40, -body_h*0.05])
        rounded_box([42, 7, 7], 3);
    translate([0, body_w*0.40, -body_h*0.05])
        rounded_box([42, 7, 7], 3);
}

module side_grips() {
    for (x=[-body_len*0.49, body_len*0.49]) {
        translate([x, -12, -1]) rounded_box([5, 13, 8], 2);
        translate([x, 12, -1]) rounded_box([5, 13, 8], 2);
    }
}

module front_led() {
    translate([0, -body_w*0.515, body_h*0.07])
        rounded_box([34, 3.4, 3.0], 1.6);
}

module sos_button() {
    translate([0, body_w*0.18, body_h*0.46])
        scale([1,1,0.22])
            cylinder(h=3.2, r=6.0, center=true);
}

module screw_markers() {
    for (x=[-body_len*0.34, body_len*0.34])
    for (y=[-body_w*0.31, body_w*0.31])
        translate([x,y,body_h*0.42])
            cylinder(h=2.0, r=1.7, center=true);
}

module top_logo_plate() {
    translate([0, 0, body_h*0.49])
        scale([1,1,0.08])
            rounded_box([28, 18, 1.3], 4);
}

module save_swimmer_lite_v002() {
    union() {
        main_shell();
        top_lid();
        lower_clip();
        side_grips();
        front_led();
        sos_button();
        screw_markers();
        top_logo_plate();
    }
}

save_swimmer_lite_v002();

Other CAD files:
diseno_3d/SS-CARCASA-LITE-MOCKUP-V001/SS-CARCASA-LITE-MOCKUP-V001.scad
diseno_3d/SS-CARCASA-LITE-MOCKUP-V001/SS-CARCASA-LITE-MOCKUP-V001.dxf
diseno_3d/SS-CARCASA-LITE-MOCKUP-V001/SS-CARCASA-LITE-MOCKUP-V001.obj
diseno_3d/SS-CARCASA-LITE-MOCKUP-V002/SS-CARCASA-LITE-MOCKUP-V002.dxf
diseno_3d/SS-CARCASA-LITE-MOCKUP-V002/SS-CARCASA-LITE-MOCKUP-V002.obj

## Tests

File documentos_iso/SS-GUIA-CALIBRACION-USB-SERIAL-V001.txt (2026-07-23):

SAVE SWIMMER
GUIA RAPIDA - CALIBRACION USB SERIAL
Version: V001
Fecha: 2026-07-08

Objetivo
Leer en vivo los datos JSON del ESP32 por USB para calibrar la interpretacion de:
- rotacion dorsal
- alineacion corporal
- energia del movimiento / MAG
- respuesta del sensor ante movimientos especificos

Herramienta
Archivo para abrir:
herramientas\CALIBRACION_USB_SERIAL.bat

Archivo principal:
herramientas\calibracion_usb_serial_v001.ps1

Uso basico
1. Conectar el ESP32 a la laptop por USB.
2. Abrir herramientas\CALIBRACION_USB_SERIAL.bat.
3. Elegir el puerto COM que corresponda al ESP32.
4. Dejar el dispositivo quieto sobre una base estable.
5. Esperar 3 segundos y presionar B para tomar base.
6. Ejecutar movimientos guiados por fase.
7. Presionar Q para cerrar.

Teclas de fase
B = tomar base con ultimos segundos
1 = quieto / mesa
2 = rotacion derecha
3 = rotacion izquierda
4 = alineacion UD / cabeza-cuerpo
5 = impulso MAG
Q = cerrar calibracion

Archivos generados
La herramienta crea una carpeta:
calibracion_usb

Dentro guarda:
- CSV completo de lectura en vivo
- TXT resumen de la calibracion

Uso recomendado de prueba
Primero hacer una sesion corta:
1. Base quieta.
2. 10 movimientos de rotacion derecha.
3. 10 movimientos de rotacion izquierda.
4. 10 movimientos de alineacion arriba/abajo.
5. 10 movimientos de impulso.

Nota tecnica
Esta calibracion es para interpretar el montaje actual del prototipo. Si cambia la posicion fisica del IMU dentro de la carcasa, se debe repetir la calibracion.

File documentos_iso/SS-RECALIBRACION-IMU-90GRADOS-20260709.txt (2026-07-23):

SAVE SWIMMER
RECALIBRACION IMU GIRADO 90 GRADOS
Fecha: 2026-07-09
Firmware: SS-LITE-BLE-SD-V1-052
Dispositivo: SS-LT-000001

Contexto
Se reubica/evalua el MPU6050 con montaje girado 90 grados respecto del montaje anterior. El objetivo es entender como cambian los ejes utiles para interpretacion corporal antes de declarar cualquier patron como aprendido.

Archivos analizados
- SS000002.CSV - imu a 90 elevacion der
- SS000003.CSV - imu a 90 elevacion izq
- SS000004.CSV - imu a 90 cabeza arriba
- SS000005 (1).CSV - imu a 90 cabeza abajo

Criterio de lectura
Se ignoran muestras iniciales inestables y muestras marcadas como NO_SENSOR. Para interpretar movimiento se priorizan picos utiles/percentiles y no solo promedios, porque el promedio aplana movimientos repetidos.

Resultado principal
Con el IMU girado 90 grados, la interpretacion de ejes cambia:

1. Rolido / elevacion derecha-izquierda
- Elevacion derecha muestra FB positivo dominante.
- Elevacion izquierda muestra FB negativo dominante.
- Por lo tanto, para este montaje el eje principal de rolido pasa a ser FB, no LR.

2. Cabeza arriba / cabeza abajo / alineacion
- Cabeza arriba muestra LR negativo dominante.
- Cabeza abajo muestra LR positivo dominante.
- Por lo tanto, para este montaje la alineacion cabeza-cuerpo pasa a leerse principalmente desde LR, con signo invertible segun como se quiera mostrar en la app.

3. UD
- UD queda muy influido por gravedad/base y variaciones de movimiento.
- En este montaje no conviene usar UD solo para clasificar rolido lateral.
- UD puede seguir ayudando como contexto de orientacion general, pero no debe ser el eje principal de rolido.

Datos resumidos por picos utiles

SS000002 - imu a 90 elevacion der:
- FB p10/p50/p90: 0.45 / 2.80 / 9.19
- LR p10/p50/p90: -0.49 / -0.25 / 0.89
- Lectura: movimiento derecho se expresa claramente como FB positivo.

SS000003 - imu a 90 elevacion izq:
- FB p10/p50/p90: -9.68 / -1.89 / 0.47
- LR p10/p50/p90: -0.53 / -0.37 / -0.17
- Lectura: movimiento izquierdo se expresa claramente como FB negativo.

SS000004 - imu a 90 cabeza arriba:
- LR p10/p50/p90: -8.86 / -4.55 / -0.44
- FB p10/p50/p90: 0.04 / 0.49 / 0.80
- Lectura: cabeza arriba/alineacion hacia arriba se expresa principalmente como LR negativo.

SS000005 - imu a 90 cabeza abajo:
- LR p10/p50/p90: -0.33 / 4.54 / 10.33
- FB p10/p50/p90: -0.69 / 0.08 / 0.53
- Lectura: cabeza abajo/alineacion hacia abajo se expresa principalmente como LR positivo.

Mapeo experimental propuesto
Para este montaje IMU 90 grados:

- ROTACION_DORSAL_RAW = FB
- ROTACION_DER = FB positivo
- ROTACION_IZQ = FB negativo
- ALINEACION_RAW = -LR si se quiere que cabeza arriba sea positivo
- ALINEACION_ARRIBA = LR negativo
- ALINEACION_ABAJO = LR positivo
- UD queda como eje auxiliar de orientacion/estabilidad

Pendiente antes de declarar aprendido
Esta recalibracion todavia es experimental. Se debe repetir:
- base de mesa
- elevacion derecha
- elevacion izquierda
- cabeza arriba
- cabeza abajo
- movimientos combinados
- prueba con dispositivo colocado
- prueba en agua/piscina

Conclusion
La reubicacion/giro del IMU no impide interpretar el movimiento. Al contrario, permite centrar mejor el sensor fisicamente, pero exige remapear los ejes en firmware/app. En este montaje, el rolido debe leerse desde FB y la alineacion cabeza-cuerpo desde LR. No se debe marcar como patron aprendido hasta repetir datos en campo y agua.

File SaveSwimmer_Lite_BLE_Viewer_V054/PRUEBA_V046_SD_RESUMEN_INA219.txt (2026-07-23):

SAVE SWIMMER - PRUEBA V046 SD + RESUMEN + INA219
================================================

Firmware:
SS-LITE-BLE-SD-V1-046

Objetivo de la version:
- Mantener CSV crudo tecnico a 10 Hz en microSD.
- Evitar pausas largas por readback/remontaje durante la sesion.
- Crear resumen rapido SMxxxxxx.CSV con muestra representativa cada 5 segundos.
- Descargar por BLE el resumen rapido como flujo normal.
- Dejar el CSV completo como descarga diagnostica lenta o retiro directo de microSD.

Al iniciar, el monitor serial debe mostrar:
- I2C DEVICE FOUND AT 0x40
- I2C DEVICE FOUND AT 0x68
- INA219 CONNECTED
- MPU6050 CONNECTED

Al cerrar sesion, la app debe informar:
- SESSION:STOPPED
- FILE=/SSxxxxxx.CSV
- SUMMARY=/SMxxxxxx.CSV
- SUMMARY_CLEAN=YES

Archivos esperados en microSD:
- SSxxxxxx.CSV = sesion completa cruda
- SMxxxxxx.CSV = resumen liviano para app
- INDEX.CSV
- BOOT.CSV

App recomendada:
Save Swimmer Field Viewer FIELD V0.3.35

Prueba minima:
1. Cargar V046 al ESP.
2. Instalar FIELD V0.3.35.
3. Iniciar sesion de 10 minutos con bateria.
4. Cerrar sesion.
5. Descargar "resumen rapido por BLE".
6. Medir tiempo de descarga.
7. Revisar si el CSV completo tiene menos pausas #SD_GAP que V045.

Criterio esperado:
- El resumen debe descargar en segundos o pocos minutos, no en 35 minutos.
- El CSV completo debe conservar mas continuidad que V045.
- CURRENT_MA y POWER_MW deben seguir presentes en CSV crudo y resumen.

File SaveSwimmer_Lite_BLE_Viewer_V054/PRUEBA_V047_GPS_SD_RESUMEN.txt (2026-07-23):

SAVE SWIMMER - PRUEBA V047 GPS + SD + RESUMEN
=============================================

Firmware:
SS-LITE-BLE-SD-V1-047

Hardware incluido:
- ESP32-S3
- MPU6050
- INA219
- microSD
- GPS NEO-M9N/GY-GPS6MV2
- BLE

GPS confirmado en test V002:
- RX ESP32: GPIO17
- TX ESP32: GPIO18
- Baud: 38400

Conexion GPS:
GPS VCC -> ESP32 3V3
GPS GND -> GND comun
GPS TX  -> ESP32 GPIO17
GPS RX  -> ESP32 GPIO18

Al iniciar, monitor serie 115200 debe mostrar:
- SS-LITE-BLE-SD-V1-047
- GPS UART READY
- GPS BAUD: 38400
- INA219 CONNECTED
- MPU6050 CONNECTED
- MICROSD READY

Serial JSON agrega:
- GPS_STATUS
- GPS_FIX
- GPS_SATS
- GPS_HDOP
- LAT
- LON
- SPEED_KMH
- GPS_AGE_MS

CSV crudo SSxxxxxx.CSV agrega:
- gps_status
- gps_fix
- gps_sats
- gps_hdop
- gps_lat
- gps_lon
- gps_speed_kmh
- gps_course
- gps_age_ms

Resumen rapido SMxxxxxx.CSV tambien agrega los mismos datos GPS.

Prueba recomendada:
1. Encender con antena GPS mirando al cielo o cerca de ventana.
2. Esperar en monitor serie hasta ver GPS_FIX=1 o GPS_STATUS=FIX.
3. Conectar Field Viewer.
4. Enviar perfil: GPS_V047_TEST.
5. Iniciar sesion de 5 a 10 minutos.
6. Mover el dispositivo o caminar si es posible.
7. Detener sesion.
8. Descargar "resumen rapido por BLE".
9. Retirar microSD solo si queremos revisar el CSV crudo completo.

Criterios esperados:
- gps_fix = 1 cuando haya posicion valida.
- gps_sats idealmente >= 6.
- gps_hdop idealmente menor a 2.0.
- gps_age_ms debe mantenerse bajo si hay fix reciente.
- El resumen debe descargar mucho mas rapido que el CSV completo.

Nota:
El paquete BLE de movimiento A:LR,FB,UD,MAG no cambia en V047.
La ubicacion GPS queda en Serial JSON, STATUS?, CSV crudo y resumen.

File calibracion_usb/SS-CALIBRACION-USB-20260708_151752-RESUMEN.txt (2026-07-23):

SAVE SWIMMER - RESUMEN CALIBRACION USB
Fecha: 2026-07-08 15:18:47
Puerto: COM3
Baud: 115200
Log: calibracion_usb\SS-CALIBRACION-USB-20260708_151752.csv

Muestras JSON: 0
Lineas totales leidas: 0

Base:
LR 0.000 | FB 0.000 | UD 0.000 | MAG 0.000 | PITCH 0.00 | ROLL 0.00

Fases:
LIBRE: muestras 0, rot der max 0.0, rot izq max 0.0, alineacion max 0.0, energia MAG max 0.00
ROT_DERECHA: muestras 0, rot der max 0.0, rot izq max 0.0, alineacion max 0.0, energia MAG max 0.00

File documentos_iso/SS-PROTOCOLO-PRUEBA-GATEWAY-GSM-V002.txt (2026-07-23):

SAVE SWIMMER - PROTOCOLO PRUEBA GATEWAY GSM V002
Fecha: 2026-06-27

Objetivo:
Simular comunicacion de campo usando el telefono A como gateway temporal: ESP por BLE -> telefono A -> datos moviles/ngrok/backend -> telefono B Coach Live.

Cambio principal respecto a V001:
- El GPS del ESP ya existe en firmware V050 y se transmite por BLE en paquetes G:.
- El GPS del telefono queda como respaldo identificado, no como ubicacion silenciosa del nadador.
- Se documenta modo EXTREMO y modo CAMPO OPTIMIZADO para controlar datos, requests y bateria.

Versiones:
- Firmware: SS-LITE-BLE-SD-V1-050.
- Field Viewer tecnico: V0.3.38 OPT.
- Coach Live: V0.1.15 OPT.
- Backend: endpoint /api/coach-live.

Modo EXTREMO / laboratorio:
- Uso: romper limites, medir consumo y saturacion.
- Frecuencia historica: POST/GET aprox cada 1 s.
- Hallazgo: captura ngrok del 2026-06-27 muestra aprox 20 requests en 13 s (~1.5 req/s).
- Impacto: con 20k requests teoricos, autonomia de tunel aprox 3.7 h.
- Valor: define techo de consumo y demuestra que el producto final no debe transmitir todo crudo permanentemente.

Modo CAMPO OPTIMIZADO:
- Field Viewer envia POST /api/telemetry cada 5 s.
- Coach Live consulta GET /api/coach-live cada 5 s.
- /api/coach-live agrupa devices + active + telemetry en una sola respuesta.
- Resultado esperado: menor uso de datos, menos requests, mejor autonomia de pruebas con ngrok/backend.

Fuente de ubicacion:
1. Si ESP GPS tiene FIX valido: usar GPS ESP como ubicacion del dispositivo.
2. Si ESP GPS no tiene FIX: usar GPS telefono solo como respaldo de prueba y mostrarlo como GPS telefono.
3. En app/coach nunca presentar GPS telefono como si fuera ubicacion confirmada del dispositivo.

Reglas iniciales de mapa:
- SIN GPS: no dibujar atleta como confirmado.
- FIX debil: mostrar punto de baja confianza.
- FIX confiable: trazar ruta y calcular distancia.
- Perdida de fix: conservar ultima ubicacion y mostrar edad de senal.

Datos transmitidos en modo optimizado:
- serial, user, mode, timestamp
- lat/lon si hay fuente disponible
- gpsSource ESP/PHONE
- gpsFix, satelites, HDOP, edad del fix si viene del ESP
- LR/FB/UD/MAG resumidos para graficas tecnicas
- motion, risk, battery, water

Criterios de exito:
- Telefono B ve actualizacion cada 5 s aprox.
- El mapa muestra ruta cuando hay GPS valido.
- La app informa fuente GPS sin ambiguedad.
- La prueba no consume la cuota del tunel en pocas horas.

Pendientes:
- Cola offline en telefono A si no hay internet.
- Servicio foreground/WakeLock real para pruebas largas.
- Modo alerta con frecuencia temporal 1-2 s.
- Resumen automatico de sesion sin descargar CSV completo.
- Mapa de confianza de comunicacion observada.

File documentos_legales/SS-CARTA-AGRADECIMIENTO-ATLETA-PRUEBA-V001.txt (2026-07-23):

SAVE SWIMMER
CARTA DE AGRADECIMIENTO AL ATLETA COLABORADOR
Version V001 - 08/07/2026

Hola ______________________________,

Queremos agradecerte sinceramente por participar en una toma de datos del proyecto Save Swimmer.

Tu colaboracion nos ayuda a construir y mejorar un dispositivo pensado para nadadores de aguas abiertas, con foco principal en seguridad, ubicacion, movimiento y alerta temprana ante situaciones de riesgo.

Cada prueba nos permite entender mejor como se mueve el cuerpo al nadar, como se comporta el dispositivo en condiciones reales y que informacion puede ser realmente util para el atleta, el entrenador y la familia.

Save Swimmer se encuentra en etapa de desarrollo y validacion. Tu participacion no solo aporta datos: tambien ayuda a darle forma a una herramienta que buscamos construir desde la experiencia real de quienes nadan.

Datos de la prueba:

Fecha: ____ / ____ / ______
Lugar: __________________________________________
Codigo(s) de sesion: _____________________________
Observaciones: ___________________________________

Si deseas seguir el avance del proyecto, puedes encontrarnos como Save Swimmer en redes sociales:

Instagram: https://www.instagram.com/saveswimmer/
TikTok: https://www.tiktok.com/@saveswimmer
Facebook: Save Swimmer
Correo: saveswimmer@gmail.com

Si deseas apoyar el desarrollo del prototipo, puedes hacerlo de forma voluntaria por Plin:

Plin Save Swimmer: 903 338 442

Tu apoyo puede ser economico, compartiendo el proyecto, respondiendo encuestas, dando feedback o conectandonos con nadadores, entrenadores o espacios donde podamos seguir probando.

Gracias por ser parte de esta etapa.

Probamos hoy para proteger manana.

Save Swimmer
Victor Loza

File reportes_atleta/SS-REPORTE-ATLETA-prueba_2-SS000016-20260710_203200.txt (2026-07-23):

SAVE SWIMMER - REPORTE AUTOMÁTICO DE SESIÓN
Atleta: prueba 2
Archivo: SS000016.CSV
Duración: 00:46 | Muestras: 308
Tipo de sesión: PRUEBA_TECNICA | prueba técnica: hubo movimiento útil, pero no alcanza para llamarlo nado continuo.

Rotación: asimetría. un lado giró más que el otro. Lado dominante: IZQ.
Alineación: estable. el cuerpo se mantuvo bastante parejo.
Impulso: suave. empuje suave; puede ser nado tranquilo o poca energía de impulso.
Ritmo: sin nado confirmado | Movimientos detectados: 6
GPS: 6 puntos válidos | Distancia aproximada: 1 m
Mejor tramo: 00:00 a 00:30
Cambio observado: al final cambió la alineación; revisar si aparece cansancio.

Nota: lectura técnica/deportiva experimental. No es diagnóstico médico.

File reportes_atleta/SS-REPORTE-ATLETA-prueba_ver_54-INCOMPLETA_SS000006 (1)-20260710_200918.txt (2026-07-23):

SAVE SWIMMER - REPORTE AUTOMÁTICO DE SESIÓN
Atleta: prueba ver 54
Archivo: INCOMPLETA_SS000006 (1).CSV
Duración: 00:50 | Muestras: 434
Tipo de sesión: PRUEBA_TECNICA | prueba técnica: hubo movimiento útil, pero no alcanza para llamarlo nado continuo.

Rotación: asimetría. un lado giró más que el otro. Lado dominante: IZQ.
Alineación: estable. el cuerpo se mantuvo bastante parejo.
Impulso: alto. hubo picos fuertes; mirar si fue fuerza útil o movimiento brusco.
Ritmo: sin nado confirmado | Movimientos detectados: 31
GPS: 434 puntos válidos | Distancia aproximada: 8 m
Mejor tramo: 00:30 a 01:00
Cambio observado: no hubo un cambio fuerte entre inicio y final.

Nota: lectura técnica/deportiva experimental. No es diagnóstico médico.

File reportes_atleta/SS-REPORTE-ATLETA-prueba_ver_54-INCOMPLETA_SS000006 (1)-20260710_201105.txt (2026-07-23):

SAVE SWIMMER - REPORTE AUTOMÁTICO DE SESIÓN
Atleta: prueba ver 54
Archivo: INCOMPLETA_SS000006 (1).CSV
Duración: 00:50 | Muestras: 417
Tipo de sesión: NADO_PROBABLE | sesión compatible con nado: se detectó alternancia, energía y ciclos suficientes.

Rotación: asimetría. un lado giró más que el otro. Lado dominante: IZQ.
Alineación: estable. el cuerpo se mantuvo bastante parejo.
Impulso: alto. hubo picos fuertes; mirar si fue fuerza útil o movimiento brusco.
Ritmo: 1.6 s/ciclo | Brazadas/ciclos detectados: 29
GPS: 417 puntos válidos | Distancia aproximada: 8 m
Mejor tramo: 00:30 a 01:00
Cambio observado: no hubo un cambio fuerte entre inicio y final.

Nota: lectura técnica/deportiva experimental. No es diagnóstico médico.

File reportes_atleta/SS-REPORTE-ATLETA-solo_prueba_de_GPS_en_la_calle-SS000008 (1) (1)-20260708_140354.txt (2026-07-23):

SAVE SWIMMER - REPORTE AUTOMÁTICO DE SESIÓN
Atleta: solo prueba de GPS en la calle
Archivo: SS000008 (1) (1).CSV
Duración: 16:08 | Muestras: 7651

Rotación: baja. giraste poco el cuerpo; puede faltar rolido para preparar mejor la brazada.
Alineación: irregular. hubo mucha variación; puede aparecer cansancio o pérdida de línea corporal.
Impulso: alto. hubo picos fuertes; mirar si fue fuerza útil o movimiento brusco.
Ritmo: 2.3 s/ciclo | Brazadas/ciclos detectados: 417
GPS: 0 puntos válidos | Distancia aproximada: 0 m
Mejor tramo: 15:50 a 16:20
Cambio observado: no hubo un cambio fuerte entre inicio y final.

Nota: lectura técnica/deportiva experimental. No es diagnóstico médico.

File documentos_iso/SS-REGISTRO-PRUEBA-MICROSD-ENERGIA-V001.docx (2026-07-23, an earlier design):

SAVE SWIMMER

# REGISTRO DE PRUEBA - MICROSD Y ALIMENTACION PORTATIL

Validacion funcional del prototipo Data Logger

Codigo | SS-PR-20260526-SD-001 | Version | V001
Fecha | 26/05/2026 | Estado | Prueba validada - alcance limitado
Responsable | Vittorio King | Proyecto | Save Swimmer Lite
Firmware | SS-LITE-BLE-SD-V1-029 | Dispositivo | SS-LT-000001

# 1. Objetivo

Confirmar que el prototipo puede registrar multiples sesiones consecutivas en microSD, asociadas a perfiles enviados desde la aplicacion BLE, funcionando con alimentacion portatil y sin depender de cable USB.

# 2. Configuracion evaluada

Bloque | Configuracion observada
Control principal | ESP32-S3 DevKit N16R8
Sensor | MPU6050 activo, datos IMU presentes en CSV
Almacenamiento | Modulo microSD SPI, CS 10 / MOSI 11 / SCK 12 / MISO 13
Alimentacion de microSD | VCC conectado a 5 V
Alimentacion general | Bateria con elevador MT3608; ESP sin conexion USB durante prueba
Aplicacion | Field Viewer BLE para perfil e inicio/detencion de sesion

# 3. Antecedente de falla y correccion aplicada

En pruebas previas, el modulo microSD fue alimentado a 3.3 V y se observaron fallas de inicio, archivos cortados y contenido corrupto. El modulo empleado dispone de adaptacion/regulacion para uso con alimentacion de 5 V. Al cambiar VCC de la microSD a 5 V y utilizar firmware V029, la grabacion de sesiones consecutivas produjo archivos CSV legibles.

Criterio tecnico actual: mantener el modulo microSD de prototipo alimentado a 5 V; conservar GND comun y pines SPI definidos. Esta validacion no reemplaza futuras pruebas de regulacion, autonomia ni PCB integrada.

# 4. Resultados obtenidos

Archivo | Perfil | Inicio local | Duracion | Muestras | Bytes | Resultado
SS000001.CSV | vitto | 09:40:18 | 26.67 s | 232 | 19,394 | VALIDA
SS000002.CSV | vittoka | 09:40:55 | 25.17 s | 242 | 20,313 | VALIDA
SS000003.CSV | vprueba 3 | 09:41:32 | 30.55 s | 304 | 25,452 | VALIDA
SS000004.CSV | 5 minutos | 09:47:35 | 236.89 s | 2,276 | 191,692 | VALIDA
SS000005.CSV | 2 minutos ms app | 09:52:54 | 93.71 s | 908 | 76,481 | VALIDA

## Archivos de control observados:

Archivo | Bytes | Validacion
BOOT.CSV | 28 | Legible; registra firmware V029. Fecha FAT 1980 esperable antes de sincronizar hora.
INDEX.CSV | 38 | Legible; contiene secuencia de sesiones 1 a 5.

# 5. Verificaciones de integridad realizadas

Control | Resultado
Lectura de encabezado CSV | Correcta en las cinco sesiones
Perfil por sesion | Perfiles diferenciados y asociados al archivo correcto
Fecha/hora desde telefono | Presente y coherente en las sesiones
Datos MPU6050 | Presentes en filas LR, FB, UD y MAG
Caracteres corruptos / bytes nulos | No observados en BOOT, INDEX ni archivos de sesion
Numeracion consecutiva | Correcta: SS000001 a SS000005

# 6. Conclusion de la prueba

RESULTADO: APROBADA PARA EL ALCANCE EVALUADO.

El prototipo registro correctamente tres sesiones cortas consecutivas y dos sesiones adicionales utilizando bateria, BLE, MPU6050 y microSD alimentada a 5 V. La cuarta sesion sostuvo casi cuatro minutos de registro SD. Queda validado el flujo basico: enviar perfil, iniciar sesion, guardar CSV independiente, detener y repetir con otro perfil.

# 7. Comparacion entre registro de app y microSD

La sesion SS000005.CSV corresponde al archivo exportado desde la app ss_2_minutos_ms_app_test_nado_20260526_095423.csv: ambos comparten el perfil '2 minutos ms app' y el inicio local 09:52:54.

Metrica | App BLE | MicroSD dispositivo | Interpretacion
Muestras | 178 | 908 | La SD conserva aproximadamente 5.1 veces mas informacion
Duracion observada | 89.15 s | 93.46 s | La app dejo de guardar antes del cierre final en SD
Frecuencia aproximada | 1.99 Hz | 9.70 Hz | BLE sirve para vivo; SD para analisis tecnico
UD maximo | 17.90 | 17.93 | Pico principal consistente
MAG maximo | 18.50 | 20.25 | La SD capta picos entre envios BLE

La comparacion temporal arrojo diferencias pequenas para FB, UD y MAG (RMSE aproximado 0.15, 0.36 y 0.27). LR tiene mayor diferencia aproximada (1.00) porque cambia con rapidez y el BLE recibe cerca de una de cada cinco muestras que quedan guardadas en la SD.

# 8. Alcances no validados aun

Pendiente | Prueba requerida
Grabacion continua prolongada | Sesion de 15 minutos y luego de 30 minutos con bateria
Repeticion intensiva | Varias sesiones seguidas sin retirar tarjeta
Autonomia real | Medir duracion de bateria con BLE y microSD activos
Estabilidad energetica | Agregar capacitor cercano a microSD y comparar resultados
Uso acuatico | No aprobado aun; requiere carcasa y protocolo de sellado/seguridad

# 9. Evidencia y trazabilidad

Los archivos fuente fueron copiados desde la microSD al proyecto para preservar evidencia. BOOT.CSV, INDEX.CSV y las sesiones 1 a 3 se conservan en datasets/evidencia/SS-PR-20260526-SD-001. Las sesiones 4 y 5, junto al CSV exportado por la app y la tabla comparativa, se conservan en datasets/evidencia/SS-PR-20260526-SD-002.

Cada carpeta contiene SHA256.csv con las huellas digitales de los archivos copiados. Registro tabular asociado: SS-BITACORA-PRUEBAS-PROTOTIPO-V001.csv.

Revision | Fecha | Descripcion | Responsable
V001 | 26/05/2026 | Validacion microSD a 5 V, bateria, cinco sesiones con V029 y comparacion app/SD. | Save Swimmer / Vittorio King

Save Swimmer | SS-PR-20260526-SD-001 | Registro de prototipo | V001

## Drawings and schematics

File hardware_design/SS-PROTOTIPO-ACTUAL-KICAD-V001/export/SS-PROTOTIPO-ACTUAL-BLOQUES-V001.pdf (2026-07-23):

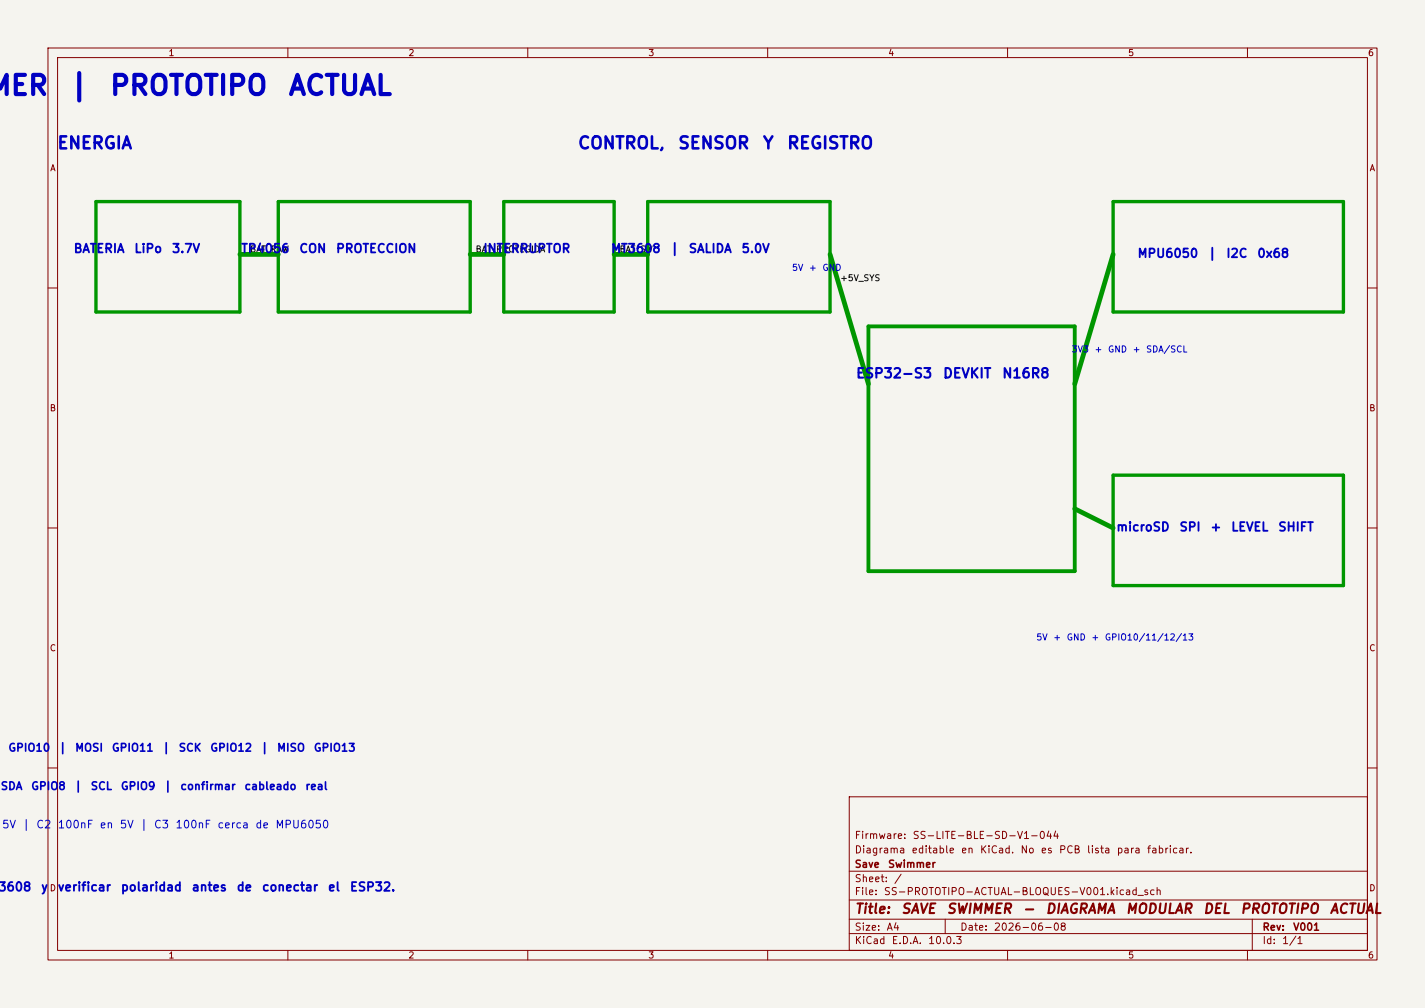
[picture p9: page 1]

SAVE SWIMMER | PROTOTIPO ACTUAL

SPI CONFIRMADO: CS GPIO10 | MOSI GPIO11 | SCK GPIO12 | MISO GPIO13

C1 1000uF cerca de 5V | C2 100nF en 5V | C3 100nF cerca de MPU6050

Firmware: SS-LITE-BLE-SD-V1-044
Diagrama editable en KiCad. No es PCB lista para fabricar.
Save Swimmer
Sheet: /
File: SS-PROTOTIPO-ACTUAL-BLOQUES-V001.kicad_sch
Title: SAVE SWIMMER - DIAGRAMA MODULAR DEL PROTOTIPO ACTUAL

ADVERTENCIA: ajustar MT3608 y verificar polaridad antes de conectar el ESP32.

Size: A4 | Rev: V001
KiCad E.D.A. 10.0.3 | Id: 1/1

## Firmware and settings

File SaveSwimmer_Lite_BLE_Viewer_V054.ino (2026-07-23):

/*
====================================================
SAVE SWIMMER
FIRMWARE: SS-LITE-BLE-SD-V1-054
DEVICE: SS-LT-000001
====================================================
ESP32-S3 + MPU6050 + INA219 + GPS + BLE + MICROSD + SERIAL JSON
Compatible con Save Swimmer Field Viewer Android
====================================================

CHANGELOG V1-054:
- Agrega rot_deg, align_deg y rot_zone al CSV/JSON para alinear firmware, app y reportes.
- Mantiene el ESP como generador de datos/contexto; la interpretacion deportiva queda en app/reporte.

BASE V1-052:
- Agrega diagnostico #TIME_GAP cuando el muestreo se atrasa durante una sesion.
- Registra fila previa, siguiente fila, gap en ms y hora local dentro del CSV.
- Agrega conteo de gaps y gap maximo al cierre de sesion.
- Ayuda a distinguir salto de datos, pausa de loop, SD/BLE o bloqueo temporal.

BASE V1-051:
- Integra modulo RGB HW-479 como indicador visual de estado.
- Usa GPIO 4/5/6 para R/G/B con pulsos no bloqueantes.
- Indica arranque, BLE, GPS/listo, grabacion, error SD/sensor y alerta.
- Pensado para prototipo; en version final debe ir con difusor visible 360.

BASE V1-050:
- GPS BLE alternado para mapa en vivo y resumen SD.
- Mantiene GPS/INA219/microSD/BLE con paquetes ultracortos.

CHANGELOG V1-047:
- Integra GPS NEO-M9N/GY-GPS6MV2 por UART1 a 38400 baudios.
- Registra fix, satelites, HDOP, latitud, longitud, velocidad y edad del fix.
- Agrega datos GPS al CSV crudo, resumen rapido y Serial JSON.
- Mantiene BLE ultracorto para movimiento; ubicacion queda en SD/resumen.

BASE V1-046:
- Prioriza continuidad de muestreo: elimina readback/remontaje despues de cada lote correcto.
- La validacion fuerte del CSV crudo se realiza al cerrar la sesion.
- Genera archivo resumen SMxxxxxx.CSV con una muestra representativa cada 5 segundos.
- Permite descargar resumen rapido o CSV crudo completo por comandos BLE separados.

BASE V1-045:
- Integra monitor de energia INA219 en el bus I2C compartido con MPU6050.
- Registra voltaje de carga, corriente y potencia en Serial JSON y microSD.
- Lee energia cada segundo para no interferir con MPU6050, BLE ni microSD.
- Conserva el paquete BLE ultracorto y la estabilidad SD de V044.

BASE V1-044:
- Verifica que el archivo crezca despues de cada flush SD.
- Si el lote no aparece en el archivo, conserva buffer y reintenta sin cortar sesion.
- Si el crecimiento es parcial, detiene por seguridad para no duplicar datos.

BASE V1-043:
- Baja el lote SD a 1 segundo para reducir perdida por fallo de escritura.
- Reduce buffer reservado y limite pendiente para reaccionar antes.
- Mantiene marcadores #SD_GAP/#SD_RESUME de V042.

BASE V1-042:
- Evita saltos numericos de fila durante recuperacion SD.
- Si hay buffer pendiente por fallo SD, pausa nuevas filas hasta persistirlo.
- Registra eventos #SD_GAP/#SD_RESUME en el CSV para analisis posterior.

BASE V1-041:
- No corta la sesion por fallo puntual al abrir lote SD.
- Conserva el buffer en RAM, remonta microSD y reintenta en el siguiente flush.
- Agrega diagnostico de fallos SD y tamano de buffer pendiente en STATUS?.

BASE V1-040:
- Registro SD conservador: flush cada 2 segundos para evitar bloques grandes.
- Durante grabacion no envia confirmacion BLE por cada lote SD.
- Reduce carga de Serial JSON mientras la microSD esta grabando.

BASE V1-039:
- Cierre limpio multi-atleta: limpia estado interno al cerrar sesion.
- Cancela transferencia BLE pendiente antes de nueva sesion/perfil.
- Remonta microSD al iniciar cada nueva sesion para evitar reiniciar ESP entre atletas.

BASE V1-038:
- No aborta la sesion por readback intermedio de tamano de archivo.
- Durante la sesion valida write/flush; la validacion fuerte queda para cierre.
- Mantiene CSV y bloque de 10 segundos para reducir escrituras.
- Reporta CHECKPOINT=WRITE_FLUSH_OK y BYTES_BEFORE/EXPECTED_BYTES.

CHANGELOG V1-037:
- Reduce bloqueos visibles: escribe microSD cada 10 segundos.
- Pausa telemetria BLE y Serial durante escritura/verificacion SD.
- Agrega metricas FLUSH_COUNT, FLUSH_MS y BUFFER_BYTES.
- No agrega GPS, temperatura ni vibrador; version enfocada solo en estabilidad SD.

CHANGELOG V1-036:
- Reduce accesos SD: escribe y confirma lotes cada 3 segundos.
- Si el readback inmediato falla, espera y relee antes de abortar la sesion.
- Como ultima verificacion remonta la microSD sin reescribir ni duplicar filas.

CHANGELOG V1-035:
- Conserva el ultimo motivo de detencion SD durante la ejecucion.
- Al reiniciar, detecta si la ultima sesion quedo sin cierre validado.
- STATUS? informa ultimo evento y motivo de reset para diagnostico en la app.

CHANGELOG V1-034:
- Escribe cada lote SD abriendo, cerrando y releyendo el archivo.
- No mantiene un stream abierto durante toda la sesion.
- Confirma el crecimiento real del archivo antes de reportar filas aseguradas.

CHANGELOG V1-033:
- Fuerza checkpoint fisico microSD cada 1 segundo durante pruebas.
- Informa filas confirmadas y bytes del lote, sin confundir lote con archivo total.
- Registra la causa de reinicio del ESP en Serial y BOOT.CSV.
- Cierra el stream y reabre el archivo para escribir/verificar el marcador final.

CHANGELOG V1-032:
- Agrega marca #END_SESSION al detener correctamente una sesion.
- Valida que todas las filas tengan columnas completas antes de confirmar guardado.
- Informa CLEAN=YES/NO al cerrar y al descargar una sesion.
- Construye cada fila completa antes de agregarla al buffer SD.

CHANGELOG V1-031:
- Permite descargar la ultima sesion cerrada de la microSD por BLE.
- Transfiere CSV por bloques confirmados para evitar perdida silenciosa.
- Pausa telemetria en vivo durante la descarga para priorizar integridad.

CHANGELOG V1-030:
- Responde PROFILE? para que la app recupere el atleta real al reconectar.
- Responde STATUS? indicando si la sesion continua activa y en que archivo.
- Rechaza cambio de perfil mientras una sesion se encuentra grabando.

CHANGELOG V1-029:
- No desmonta una SD que ya fue validada al iniciar el dispositivo.
- Solo intenta remontar la tarjeta si el arranque no la dejo disponible.
- Distingue SD_BOOT_NOT_READY de SD_RECOVERY_FAILED en la app/Serial.

CHANGELOG V1-028:
- Mantiene el CSV abierto durante la sesion y lo cierra solamente al detener.
- Reduce operaciones FAT de abrir/cerrar que podian cortar grabaciones largas.
- Baja SPI SD a 1 MHz para mejorar tolerancia al cableado del prototipo.
- Sincroniza el archivo cada 3 segundos para limitar perdida ante apagado.

CHANGELOG V1-027:
- Agrega /INDEX.CSV como contador persistente de sesiones en microSD.
- No reutiliza SS000001.CSV si la sesion anterior fue renombrada o retirada.
- INDEX.CSV es archivo de sistema del dispositivo y no debe borrarse.

CHANGELOG V1-026:
- Aplica al reloj interno del ESP la fecha/hora recibida desde el celular.
- Los CSV de sesion se crean con fecha FAT real, no 01/01/1980.
- BOOT.CSV puede mantener fecha inicial porque se escribe antes de sincronizar BLE.

CHANGELOG V1-025:
- Vuelve a lotes SD pequenos de 1 segundo: V024 fallo con el primer lote grande.
- Si falla la apertura de un lote, remonta SD y reintenta hasta dos veces.
- Reserva memoria del buffer para reducir fragmentacion durante la sesion.

CHANGELOG V1-023:
- Reinicializa el bus y montaje microSD al comenzar cada nueva sesion.
- Permite recuperacion despues de una sesion cerrada o tarjeta reinsertada.
- Mantiene muestreo 10 Hz y escritura estable por lotes de 1 segundo.

CHANGELOG V1-022:
- Conserva muestreo a 10 Hz, pero acumula filas en RAM y escribe SD cada 1 segundo.
- Evita abrir/cerrar/releer la tarjeta diez veces por segundo.
- Al detener, guarda cualquier lote pendiente antes de cerrar sesion.

CHANGELOG V1-021:
- La sesion escribe con archivos locales abrir-escribir-cerrar, igual que BOOT.CSV.
- Evita mantener un File global abierto entre telemetria BLE y escritura SD.
- Reporta bytes reales del encabezado y de las filas ya persistidas.

CHANGELOG V1-020:
- Crea el CSV de sesion con FILE_APPEND, igual que BOOT.CSV validado.
- Corrige archivos SS00000X.CSV creados en cero bytes con FILE_WRITE.

CHANGELOG V1-019:
- Procesa START/STOP de sesion en loop(), fuera del callback BLE.
- Agrega prueba /BOOT.CSV antes de iniciar BLE para diagnosticar SD integrada.
- Permite separar falla de hardware SD de conflicto durante la orden Bluetooth.

CHANGELOG V1-018:
- Reemplaza SD.exists() por verificacion real abriendo y leyendo el CSV.
- Evita falso FILE_NOT_CREATED aunque la tarjeta haya escrito correctamente.
- Selecciona nuevo nombre corto comprobando archivos mediante lectura.

CHANGELOG V1-017:
- Cambia nombre de archivo a formato FAT corto 8.3: SS000001.CSV.
- Evita fallo FILE_NOT_CREATED observado con nombres largos por fecha/atleta.
- La fecha y el perfil permanecen dentro del encabezado CSV.

CHANGELOG V1-016:
- Verifica fisicamente la creacion del CSV antes de confirmar inicio a la app.
- Confirma escritura SD cada segundo con filas grabadas.
- Al detener informa filas y bytes guardados en la tarjeta.
- Cierra/reabre el archivo periodicamente para reducir perdida por apagado o retiro accidental.

CHANGELOG V1-015:
- Integra microSD con SPI probado: CS 10, MOSI 11, SCK 12, MISO 13.
- No graba al encender: inicia/detiene sesion por comando BLE desde la app.
- La app envia fecha/hora del telefono por BLE; no depende de WiFi/NTP en playa.
- CSV por sesion con perfil, serial, firmware y telemetria real MPU6050.

CHANGELOG V1-014:
- Config BLE acepta WRITE y WRITE_NR para mejorar compatibilidad Android.

CHANGELOG V1-013:
- Config BLE mas estable: caracteristica separada para escritura.
- Desactiva Preferences temporalmente para evitar reinicio en loop.
- Mantiene perfil en RAM durante la prueba.

CHANGELOG V1-012:
- BLE bidireccional: la app puede enviar perfil de usuario.
- Guarda USER/AGE/HEIGHT/WEIGHT/MODE en memoria interna Preferences.
- Responde por BLE/Serial con confirmacion de configuracion.

CHANGELOG V1-011:
- Agrega diagnostico I2C para detectar MPU6050 en 0x68/0x69.
- Imprime aviso si el BLE funciona pero el sensor no entrega datos.

CHANGELOG V1-010:
- Paquete BLE ultracorto A:LR,FB,UD,MAG para Web Bluetooth y APK Android.
- Compatible con Save Swimmer Field Viewer Android.
- Blynk desactivado para pruebas sin consumo de cupo.
- Salida Serial JSON conservada para laboratorio.

Notas:
- Blynk queda fuera de esta version para no consumir cupo.
- La app web lee BLE en tiempo real desde Chrome/Edge.
- Serial Studio puede leer el JSON por USB.
*/

#include <Wire.h>
#include <SPI.h>
#include <SD.h>
#include <time.h>
#include <sys/time.h>

#include <Adafruit_MPU6050.h>
#include <Adafruit_Sensor.h>

#include <BLEDevice.h>
#include <BLEServer.h>
#include <BLEUtils.h>
#include <BLE2902.h>
#include <esp_system.h>

// ====================================================
// DEVICE INFO
// ====================================================

#define DEVICE_SERIAL "SS-LT-000001"
#define FIRMWARE_VERSION "SS-LITE-BLE-SD-V1-054"

// ====================================================
// SAVE SWIMMER BLE UUIDS
// Deben coincidir con save_swimmer_ble_viewer.html
// ====================================================

#define SS_SERVICE_UUID           "8f1c1000-5a7e-4b3d-9c21-a10000000001"
#define SS_TELEMETRY_CHAR_UUID    "8f1c1001-5a7e-4b3d-9c21-a10000000001"
#define SS_CONFIG_CHAR_UUID       "8f1c1002-5a7e-4b3d-9c21-a10000000001"

// ====================================================
// TIMING
// ====================================================

#define SAMPLE_RATE_MS 100
#define BLE_SEND_MS 500
#define SERIAL_SEND_MS 100
#define SD_WRITE_MS 1000
#define SD_BUFFER_RESERVE_BYTES 2000
#define SD_MAX_PENDING_BYTES 8000
#define SD_VERIFY_ATTEMPTS 3
#define SD_VERIFY_DELAY_MS 100
#define SD_SPI_HZ 1000000
#define FILE_CHUNK_BYTES 120
#define FILE_ACK_TIMEOUT_MS 1200
#define POWER_SAMPLE_MS 1000
#define SUMMARY_SAMPLE_MS 5000
#define SUMMARY_WRITE_MS 30000
#define SAMPLE_GAP_WARN_MS 400

// ====================================================
// GPS UART CONFIG
// Confirmado con SS-GPS-TEST-V002:
// GPS BAUD LOCKED: 38400
// ====================================================

#define GPS_RX_PIN 17
#define GPS_TX_PIN 18
#define GPS_BAUD 38400

// ====================================================
// RGB STATUS LED - HW-479 / KY-016
// Pin "-" del modulo a GND. Pines R/G/B a GPIO.
// El modulo HW-479 suele traer resistencias integradas.
// ====================================================

#define RGB_ENABLED true
#define RGB_COMMON_CATHODE true
#define RGB_R_PIN 4
#define RGB_G_PIN 5
#define RGB_B_PIN 6
#define RGB_PULSE_MS 80

// ====================================================
// INA219 CONFIG
// Modulo tipico con shunt de 0.1 ohm:
// corriente maxima medible aproximada 3.2 A.
// ====================================================

#define INA219_ADDRESS 0x40
#define INA219_REG_CONFIG 0x00
#define INA219_REG_SHUNT_VOLTAGE 0x01
#define INA219_REG_BUS_VOLTAGE 0x02
#define INA219_REG_POWER 0x03
#define INA219_REG_CURRENT 0x04
#define INA219_REG_CALIBRATION 0x05
#define INA219_CALIBRATION_VALUE 4096
#define INA219_CONFIG_VALUE 0x399F

// ====================================================
// OPTIONAL I2C PINS
// Si tu placa necesita pines especificos, cambia aqui.
// Si no, deja -1 para usar Wire.begin() normal.
// ====================================================

#define I2C_SDA_PIN -1
#define I2C_SCL_PIN -1

// ====================================================
// MICROSD SPI PINS
// Conexion confirmada con SS-MICROSD-TEST-V001.
// ====================================================

#define SD_CS   10
#define SD_MOSI 11
#define SD_SCK  12
#define SD_MISO 13

// ====================================================
// OBJECTS
// ====================================================

Adafruit_MPU6050 mpu;
SPIClass sdSPI(FSPI);
File transferFile;
HardwareSerial gpsSerial(1);

BLECharacteristic *pCharacteristic = nullptr;
BLECharacteristic *pConfigCharacteristic = nullptr;
bool deviceConnected = false;
bool sdReady = false;
bool sessionRecording = false;
bool sessionStartRequested = false;
bool sessionStopRequested = false;
bool downloadLastRequested = false;
bool downloadSummaryRequested = false;
bool fileTransferActive = false;
bool fileTransferWaitingAck = false;
bool sdFlushActive = false;

// ====================================================
// SYSTEM STATUS
// ====================================================

String SYSTEM_STATE = "READY";
String WATER_STATE = "NO";      // placeholder hasta agregar sensor de agua
String BODY_STATE = "UNKNOWN";
String MOTION_STATE = "UNKNOWN";
String RISK_STATE = "NORMAL";
String USER_NAME = "SIN_USUARIO";
String USER_MODE = "TEST";
String SESSION_FILE = "";
String SUMMARY_FILE = "";
String pendingSessionPayload = "";
String transferFileName = "";
String transferLastPayload = "";
String LAST_SESSION_EVENT = "NONE";
String LAST_SESSION_FILE = "";
String LAST_SUMMARY_FILE = "";

int BATTERY_LEVEL = 100;        // placeholder hasta medir bateria real
int RISK_SCORE = 0;
int USER_AGE = 0;
float USER_HEIGHT = 0;
float USER_WEIGHT = 0;

// ====================================================
// SENSOR VALUES
// ====================================================

float LR = 0;       // X
float FB = 0;       // Y
float UD = 0;       // Z
float MAG = 0;
float TIME_S = 0;

float PITCH = 0;
float ROLL = 0;
float ROT_AXIS = 0;
float ALIGN_AXIS = 0;
float ROT_DEG = 0;
float ALIGN_DEG = 0;
String ROT_ZONE = "UNKNOWN";

const char* IMU_MAP = "IMU90_FB_ROT_NEG_LR_ALIGN";

float POWER_BUS_V = 0;
float POWER_SHUNT_MV = 0;
float POWER_INPUT_V = 0;
float POWER_LOAD_V = 0;
float POWER_CURRENT_MA = 0;
float POWER_MW = 0;

String gpsNmeaLine = "";
String GPS_UTC = "NO_TIME";
String GPS_FIX_QUALITY = "0";
String GPS_SATELLITES = "0";
String GPS_HDOP = "0";
String GPS_STATUS = "NO_FIX";
float GPS_LAT = 0;
float GPS_LON = 0;
float GPS_SPEED_KMH = 0;
float GPS_COURSE = 0;
bool gpsHasFix = false;
unsigned long gpsLines = 0;
unsigned long gpsValidLines = 0;
unsigned long lastGpsByteMs = 0;
unsigned long lastGpsFixMs = 0;

// Cambia estos signos si al probar ves ejes invertidos.
// Objetivo conceptual:
// LR+ derecha del nadador
// FB+ hacia cabeza/frente
// UD+ fuera de la espalda / hacia superficie
const float LR_SIGN = 1.0;
const float FB_SIGN = 1.0;
const float UD_SIGN = 1.0;

unsigned long lastSample = 0;
unsigned long lastBleSend = 0;
unsigned long lastSerialSend = 0;
unsigned long lastPowerSample = 0;
unsigned long lastSessionSampleMs = 0;
unsigned long sampleGapCount = 0;
unsigned long maxSampleGapMs = 0;
bool bleSendGpsNext = false;
unsigned long lastSdFlush = 0;
unsigned long lastSummarySample = 0;
unsigned long lastSummaryFlush = 0;
unsigned long sessionStartMillis = 0;
unsigned long sessionStartEpoch = 0;
long sessionTimezoneOffset = -18000;
unsigned long sessionRow = 0;
unsigned long streamedSessionRows = 0;
unsigned long savedSessionRows = 0;
unsigned long transferFileBytes = 0;
unsigned long transferBytesConfirmed = 0;
unsigned long transferSequence = 0;
unsigned long transferLastSend = 0;
unsigned long sdFlushCount = 0;
unsigned long lastSdFlushDurationMs = 0;
unsigned long maxSdFlushDurationMs = 0;
unsigned long sdFlushFailCount = 0;
unsigned long lastSdFailureMs = 0;
unsigned long sdPausedSamples = 0;
unsigned long sdPauseStartedMs = 0;
bool sdRecoveryPause = false;
bool sdRecoveryMarkerPending = false;
size_t transferLastChunkBytes = 0;
String sdWriteBuffer = "";
String summaryWriteBuffer = "";

bool mpuReady = false;
bool ina219Ready = false;
unsigned long lastMpuWarning = 0;
String RESET_REASON = "UNKNOWN";

// Movimiento simple para prototipo
float magBaseline = 9.81;
float magDeltaFiltered = 0;
unsigned long lastMovementMs = 0;

// ====================================================
// RGB STATUS LED
// ====================================================

unsigned long lastRgbUpdate = 0;
bool rgbPulseOn = false;

void writeRgbPin(int pin, bool on) {
  if (!RGB_ENABLED) {
    return;
  }

  if (RGB_COMMON_CATHODE) {
    digitalWrite(pin, on ? HIGH : LOW);
  } else {
    digitalWrite(pin, on ? LOW : HIGH);
  }
}

void setRgbColor(bool red, bool green, bool blue) {
  if (!RGB_ENABLED) {
    return;
  }

  writeRgbPin(RGB_R_PIN, red);
  writeRgbPin(RGB_G_PIN, green);
  writeRgbPin(RGB_B_PIN, blue);
}

void setupRgbLed() {
  if (!RGB_ENABLED) {
    return;
  }

  pinMode(RGB_R_PIN, OUTPUT);
  pinMode(RGB_G_PIN, OUTPUT);
  pinMode(RGB_B_PIN, OUTPUT);
  setRgbColor(false, false, false);

  // Pulso corto de arranque para confirmar cableado.
  setRgbColor(false, true, true);
  delay(120);
  setRgbColor(false, false, false);
}

bool rgbPulse(unsigned long now, unsigned long periodMs, unsigned long onMs) {
  unsigned long phase = now % periodMs;
  return phase < onMs;
}

void applyRgbState(bool red, bool green, bool blue, bool on) {
  if (on) {
    setRgbColor(red, green, blue);
  } else {
    setRgbColor(false, false, false);
  }
}

void updateRgbLed() {
  if (!RGB_ENABLED) {
    return;
  }

  unsigned long now = millis();
  if (now - lastRgbUpdate < 25) {
    return;
  }
  lastRgbUpdate = now;

  bool sensorOrSdError = !mpuReady || SYSTEM_STATE == "SD_ERROR";
  bool sdUnavailable = !sdReady && !sessionRecording;
  bool activeAlert = RISK_STATE != "NORMAL" || RISK_SCORE >= 70;

  if (activeAlert) {
    // Rojo rapido: prioridad maxima.
    applyRgbState(true, false, false, rgbPulse(now, 300, 120));
    return;
  }

  if (sensorOrSdError) {
    // Rojo lento: revisar hardware/sensor/SD.
    applyRgbState(true, false, false, rgbPulse(now, 1200, RGB_PULSE_MS));
    return;
  }

  if (sdUnavailable) {
    // Naranja: sistema vivo, pero SD no lista para grabar.
    applyRgbState(true, true, false, rgbPulse(now, 1500, RGB_PULSE_MS));
    return;
  }

  if (sessionRecording) {
    // Cian: grabando datos.
    applyRgbState(false, true, true, rgbPulse(now, 900, RGB_PULSE_MS));
    return;
  }

  if (fileTransferActive) {
    // Blanco: transfiriendo archivo/resumen por BLE.
    applyRgbState(true, true, true, rgbPulse(now, 450, 90));
    return;
  }

  if (deviceConnected) {
    // Violeta: conectado por BLE, listo para comandos.
    applyRgbState(true, false, true, rgbPulse(now, 1600, RGB_PULSE_MS));
    return;
  }

  if (gpsHasFix && sdReady && mpuReady) {
    // Verde: listo con GPS/sensor/SD.
    applyRgbState(false, true, false, rgbPulse(now, 2200, RGB_PULSE_MS));
    return;
  }

  // Azul: encendido, esperando GPS/BLE/inicio.
  applyRgbState(false, false, true, rgbPulse(now, 2200, RGB_PULSE_MS));
}

// ====================================================
// BLE CALLBACKS
// ====================================================
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
void loop() {
  unsigned long now = millis();

  readGPS();
  updateRgbLed();

  if (now - lastPowerSample >= POWER_SAMPLE_MS) {
    lastPowerSample = now;
    if (!ina219Ready) {
      ina219Ready = beginINA219();
      if (ina219Ready) {
        Serial.println("INA219 RECONNECTED");
      }
    }
    readINA219();
  }

  if (downloadLastRequested) {
    downloadLastRequested = false;
    beginLatestFileTransfer();
  }

  if (downloadSummaryRequested) {
    downloadSummaryRequested = false;
    beginLatestSummaryTransfer();
  }

  serviceFileTransfer();

  if (sessionStopRequested) {
    sessionStopRequested = false;
    endSession();
  }

  if (sessionStartRequested) {
    String command = pendingSessionPayload;
    sessionStartRequested = false;
    pendingSessionPayload = "";
    beginSession(command);
  }

  if (now - lastSample >= SAMPLE_RATE_MS) {
    lastSample = now;
    readMPU6050();
    writeSessionSample();
    writeSummarySample();
  }

  if (now - lastSerialSend >= SERIAL_SEND_MS) {
    lastSerialSend = now;
    sendSerialStudio();
  }

  if (!fileTransferActive && now - lastBleSend >= BLE_SEND_MS) {
    lastBleSend = now;
    sendBleTelemetry();
  }

  updateRgbLed();
}

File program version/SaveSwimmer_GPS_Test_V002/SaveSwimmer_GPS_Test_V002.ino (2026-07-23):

/*
====================================================
SAVE SWIMMER
GPS TEST: SS-GPS-TEST-V002
DEVICE: SS-LT-000001
====================================================
ESP32-S3 + GPS NEO-M9N / GY-GPS6MV2
AUTO BAUD NMEA TEST SIN LIBRERIAS EXTERNAS
====================================================

Conexion:
GPS VCC -> ESP32 3V3
GPS GND -> ESP32 GND
GPS TX  -> ESP32 GPIO17
GPS RX  -> ESP32 GPIO18

Monitor Serie:
115200 baudios
====================================================
*/

#define DEVICE_SERIAL "SS-LT-000001"
#define TEST_VERSION "SS-GPS-TEST-V002"

#define GPS_RX_PIN 17
#define GPS_TX_PIN 18

HardwareSerial gpsSerial(1);

const long baudRates[] = {9600, 38400, 57600, 115200};
const int baudRateCount = sizeof(baudRates) / sizeof(baudRates[0]);

int currentBaudIndex = 0;
long lockedBaud = 0;
String nmeaLine = "";
unsigned long baudStartedMs = 0;
unsigned long lastStatusMs = 0;
unsigned long lastGpsByteMs = 0;
unsigned long lastGoodNmeaMs = 0;
unsigned long nmeaLines = 0;
unsigned long validLines = 0;
unsigned long garbageLines = 0;

String lastUtc = "NO_TIME";
String lastLat = "NO_LAT";
String lastLon = "NO_LON";
String lastFixQuality = "0";
String lastSatellites = "0";
String lastHdop = "0";
String lastSpeedKmh = "0";
String lastCourse = "0";

String getCsvField(const String& line, int index) {
  int current = 0;
  int start = 0;
  for (int i = 0; i <= line.length(); i++) {
    if (i == line.length() || line.charAt(i) == ',') {
      if (current == index) {
        return line.substring(start, i);
      }
      current++;
      start = i + 1;
    }
  }
  return "";
}

float nmeaCoordToDecimal(const String& raw, const String& hemisphere) {
  int dot = raw.indexOf('.');
  if (dot < 0) return 0.0;
  int degDigits = dot > 4 ? 3 : 2;
  float degrees = raw.substring(0, degDigits).toFloat();
  float minutes = raw.substring(degDigits).toFloat();
  float decimal = degrees + (minutes / 60.0);
  if (hemisphere == "S" || hemisphere == "W") decimal *= -1.0;
  return decimal;
}

bool looksLikeNmea(const String& line) {
  return line.startsWith("$GP") || line.startsWith("$GN") || line.startsWith("$GL") || line.startsWith("$GA");
}

void startGpsBaud(long baud) {
  gpsSerial.end();
  delay(100);
  nmeaLine = "";
  baudStartedMs = millis();
  Serial.println("--------------------------------");
  Serial.print("TESTING GPS BAUD: ");
  Serial.println(baud);
  gpsSerial.begin(baud, SERIAL_8N1, GPS_RX_PIN, GPS_TX_PIN);
}

void nextBaud() {
  currentBaudIndex++;
  if (currentBaudIndex >= baudRateCount) {
    currentBaudIndex = 0;
  }
  startGpsBaud(baudRates[currentBaudIndex]);
}

void parseGGA(const String& line) {
  String utc = getCsvField(line, 1);
  String latRaw = getCsvField(line, 2);
  String latHem = getCsvField(line, 3);
  String lonRaw = getCsvField(line, 4);
  String lonHem = getCsvField(line, 5);
  String quality = getCsvField(line, 6);
  String satellites = getCsvField(line, 7);
  String hdop = getCsvField(line, 8);

  if (utc.length() > 0) lastUtc = utc;
  if (quality.length() > 0) lastFixQuality = quality;
  if (satellites.length() > 0) lastSatellites = satellites;
  if (hdop.length() > 0) lastHdop = hdop;

  if (quality.toInt() > 0 && latRaw.length() > 0 && lonRaw.length() > 0) {
    lastLat = String(nmeaCoordToDecimal(latRaw, latHem), 6);
    lastLon = String(nmeaCoordToDecimal(lonRaw, lonHem), 6);
  }
}

void parseRMC(const String& line) {
  String utc = getCsvField(line, 1);
  String status = getCsvField(line, 2);
  String latRaw = getCsvField(line, 3);
  String latHem = getCsvField(line, 4);
  String lonRaw = getCsvField(line, 5);
  String lonHem = getCsvField(line, 6);
  String speedKnots = getCsvField(line, 7);
  String course = getCsvField(line, 8);

  if (utc.length() > 0) lastUtc = utc;
  if (speedKnots.length() > 0) lastSpeedKmh = String(speedKnots.toFloat() * 1.852, 2);
  if (course.length() > 0) lastCourse = course;

  if (status == "A" && latRaw.length() > 0 && lonRaw.length() > 0) {
    lastLat = String(nmeaCoordToDecimal(latRaw, latHem), 6);
    lastLon = String(nmeaCoordToDecimal(lonRaw, lonHem), 6);
  }
}

void handleLine(String line) {
  line.trim();
  if (line.length() == 0) return;

  nmeaLines++;
  if (!looksLikeNmea(line)) {
    garbageLines++;
    if (garbageLines <= 6) {
      Serial.print("GARBAGE ");
      Serial.print(garbageLines);
      Serial.print(": ");
      Serial.println(line);
    }
    return;
  }

  validLines++;
  lastGoodNmeaMs = millis();
  if (lockedBaud == 0) {
    lockedBaud = baudRates[currentBaudIndex];
    Serial.print("GPS BAUD LOCKED: ");
    Serial.println(lockedBaud);
  }

  Serial.print("NMEA OK ");
  Serial.print(validLines);
  Serial.print(": ");
  Serial.println(line);

  if (line.startsWith("$GPGGA") || line.startsWith("$GNGGA")) {
    parseGGA(line);
  } else if (line.startsWith("$GPRMC") || line.startsWith("$GNRMC")) {
    parseRMC(line);
  }
}

void printStatus() {
  Serial.println("--------------------------------");
  Serial.println("SAVE SWIMMER GPS STATUS");
  Serial.print("CURRENT BAUD: ");
  Serial.println(baudRates[currentBaudIndex]);
  Serial.print("LOCKED BAUD: ");
  Serial.println(lockedBaud > 0 ? String(lockedBaud) : "NO");
  Serial.print("GPS BYTES: ");
  Serial.println(lastGpsByteMs > 0 ? "YES" : "NO");
  Serial.print("TOTAL LINES: ");
  Serial.println(nmeaLines);
  Serial.print("VALID NMEA: ");
  Serial.println(validLines);
  Serial.print("GARBAGE LINES: ");
  Serial.println(garbageLines);
  Serial.print("UTC: ");
  Serial.println(lastUtc);
  Serial.print("FIX QUALITY: ");
  Serial.println(lastFixQuality);
  Serial.print("SATELLITES: ");
  Serial.println(lastSatellites);
  Serial.print("HDOP: ");
  Serial.println(lastHdop);
  Serial.print("LAT: ");
  Serial.println(lastLat);
  Serial.print("LON: ");
  Serial.println(lastLon);
  Serial.print("SPEED KMH: ");
  Serial.println(lastSpeedKmh);
  Serial.print("COURSE: ");
  Serial.println(lastCourse);
  Serial.println("--------------------------------");
}

void setup() {
  Serial.begin(115200);
  delay(1000);

  Serial.println("================================");
  Serial.println("SAVE SWIMMER GPS TEST STARTING");
  Serial.println(DEVICE_SERIAL);
  Serial.println(TEST_VERSION);
  Serial.print("GPS RX PIN: ");
  Serial.println(GPS_RX_PIN);
  Serial.print("GPS TX PIN: ");
  Serial.println(GPS_TX_PIN);
  Serial.println("================================");

  startGpsBaud(baudRates[currentBaudIndex]);
}
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
